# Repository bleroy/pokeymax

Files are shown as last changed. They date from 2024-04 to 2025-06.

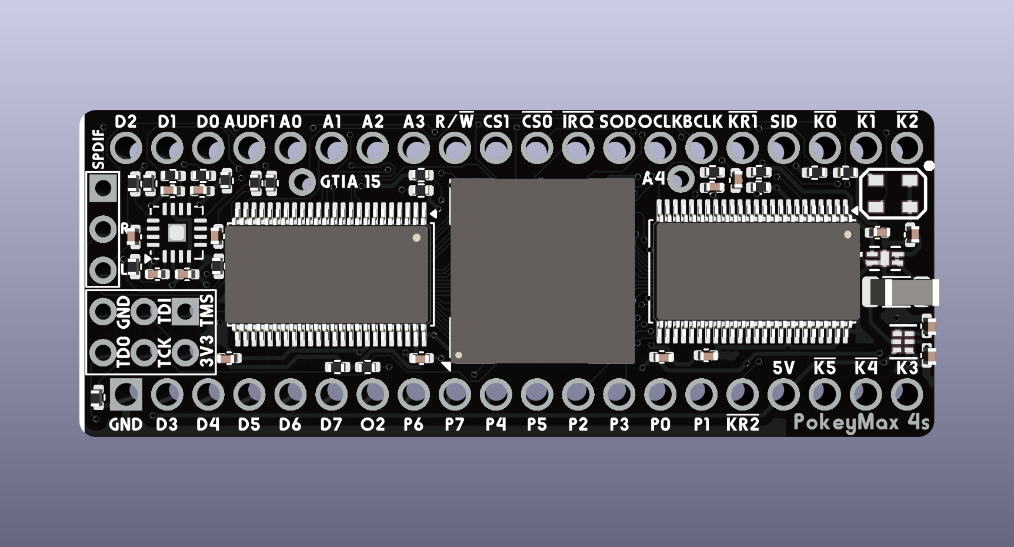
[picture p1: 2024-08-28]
PokeyMax4s/PokeyMax4s-front.png

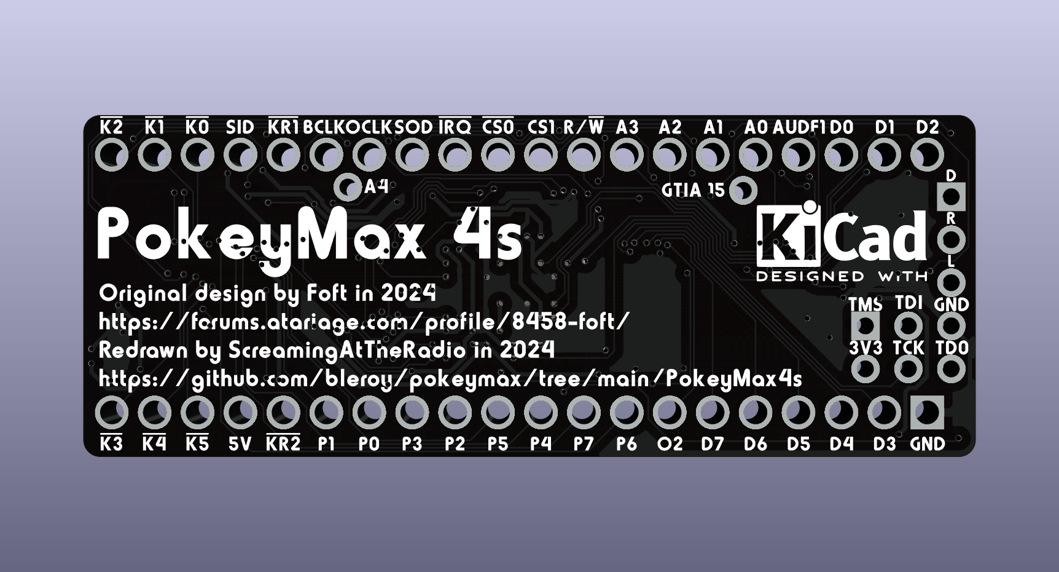
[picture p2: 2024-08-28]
PokeyMax4s/PokeyMax4s-back.png

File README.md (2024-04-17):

# PokeyMax 4

Foft's public designs for PokeyMax.

Pokeys are getting rare and expensive. FPGA alternatives exist but are also expensive. Foft, the author of PokeyMax, has very generously made his designs public on [the AtariAge forums](https://forums.atariage.com/topic/364870-pokeymax-v4-bring-up-thread/).
With his permission, I'm publishing his latest iteration on PokeyMax, version 4, which is a 2-layer version with all components on the top side. This should be easier to produce at a lower cost than the previous versions. I've also imported the project in KiCad from the original Eagle files.

Foft has not specified a license for his work, but attribution should be maintained. This is his design, reproduced here under his permission.

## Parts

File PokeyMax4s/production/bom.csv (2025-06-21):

Designator | Footprint | Quantity | Value | LCSC Part #
C1, C11, C2, C5, C6 | 0402 | 5 | 0.1uF | C60474
C10 | 0402 | 1 | 10nF | C60133
C12, C3, C4, C8 | 0402 | 4 | 2.2uF | C12530
C13, C14, C15 | 0402 | 3 | 18nF | C576736
C7 | 0402 | 1 | 1nF | C106205
C9 | 0402 | 1 | 4.7uF | C307423
FB1 | 0402 | 1 | R-EU_R0402 | C160612
L1 | 1206 | 1 | 1uH | C139248
R1, R14, R15, R16, R2, R4, R5 | 0402 | 7 | 10k | C2906885
R10, R6 | 0402 | 2 | 1k1 | C25860
R11, R12, R13 | 0402 | 3 | 560R | C2909370
R17, R18, R19 | 0402 | 3 | 20k | C25545
R3 | 0402 | 1 | 1k | C2906899
R7 | 0402 | 1 | 2k2 | C25933
R8, R9 | 0402 | 2 | 3k3 | C25936
REG1 | DRY6 | 1 | TPS62237DRYR | C398923
REG2 | TDFN4_1P2X1P6_MCH | 1 | MIC94310-JYMT-TR | C622559
U1 | VQFN-16-1EP_3x3mm_P0.5mm_EP1.1x1.1mm | 1 | TSV854IQ4T | C183029
U2, U4 | TSSOP-48_6.1x12.5mm_P0.5mm | 2 | 74CB3T16210 | C2674635
U3 | BGA-169_11.0x11.0mm_Layout13x13_P0.8mm_Ball0.5mm_Pad0.4mm_NSMD | 1 | MAX10 | C1521844
X1 | ASE | 1 | 50MHz | C7431354

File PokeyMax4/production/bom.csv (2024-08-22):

Designator | Footprint | Quantity | Value | LCSC Part #
C1, C11, C2, C5, C6 | C0402 | 5 | 0.1uF | C88219
C10 | C0402 | 1 | 0.01uF | C43253
C12, C3, C4, C8 | C0402 | 4 | 2.2uF | C43922
C13, C14, C15 | C0402 | 3 | 18nF | C107079
C7 | C0402 | 1 | 1nF | C1636
C9 | C0402 | 1 | 4.7uF | C112433
FB1 | R0402 | 1 | R-EU_R0402 | C710330
L1 | INDC1008X04 | 1 | LQM2HPN1R0MJ0L | C216157
R1, R2, R4, R5 | R0402 | 4 | 10K | C103199
R10, R6 | R0402 | 2 | 1k1 | C140120
R11, R12, R13 | 0402 | 3 | 560R
R14, R15, R16 | 0402 | 3 | 10k
R17, R18, R19 | 0402 | 3 | 20k
R3 | R0402 | 1 | 1K | C107079
R7 | R0402 | 1 | 2k2 | C294652
R8, R9 | R0402 | 2 | 3k3 | C72816
REG1 | DRY6 | 1 | TPS62237DRYR | C398923
REG2 | TDFN4_1P2X1P6_MCH | 1 | MIC94310-JYMT-TR | C622559
U1 | QFN50P300X300X100-16N | 1 | TSV854IQ4T | C2058240
U2, U4 | 56TVSOP_SMALL | 2 | SN74CB3T16211SM | C2674751
U3 | U169SMALL | 1 | MAX10 | C1521935
X1 | ASE | 1 | ASE | C7431354

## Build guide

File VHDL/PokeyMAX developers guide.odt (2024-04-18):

# PokeyMAX developers guide (for core version v1.26)

The PokeyMAX may contain several audio chips, depending on the version

## Memory map

$D200-$D20F | Pokey1
$D210-$D21F | Pokey2/Configuration
$D220-$D22F | Pokey3
$D230-$D23F | Pokey4
$D240-$D25F | SID1
$D260-$D27F | SID2
$D280-$D283 | COVOX
$D284-$D29F | SAMPLE
$D2A0-$D2AF | PSG1
$D2B0-$D2BF | PSG2
$D2C0-$D2FF | RESERVED

## Reduced memory maps

### Mono (or any PokeyMAX when in mono mode)

$D200-$D20F | Pokey1
$D210-$D2FF | Shadows of Pokey1

### Stereo

$D200-$D20F | Pokey1
$D210-$D21F | Pokey2/Configuration
$D220-$D2FF | Shadows of Pokey1, then Pokey2, then Pokey1 etc

### Stereo with covox

$D200-$D20F | Pokey1
$D210-$D21F | Pokey2/Configuration
$D220-$D27F | Shadows of Pokey1, then Pokey2, then Pokey1 etc
$D280-$D29F | COVOX
$D2A0-$D2FF | Shadows of Covox

### Quad

$D200-$D20F | Pokey1
$D210-$D21F | Pokey2/Configuration
$D220-$D22F | Pokey3
$D230-$D23F | Pokey4
$D240-$D2FF | Shadows of Pokey1, then Pokey2, then Pokey3, then Pokey4 etc

### Quad with covox

$D200-$D20F | Pokey1
$D210-$D21F | Pokey2/Configuration
$D220-$D22F | Pokey3
$D230-$D23F | Pokey4
$D240-$D27F | Shadows of Pokey1, then Pokey2, then Pokey3, then Pokey4 etc
$D280-$D29F | COVOX
$D2A0-$D2FF | Shadows of Covox

### Quad with sid

$D200-$D20F | Pokey1
$D210-$D21F | Pokey2/Configuration
$D220-$D22F | Pokey3
$D230-$D23F | Pokey4
$D240-$D25F | SID1
$D260-$D27F | SID2
$D280-$D2FF | Shadow of all above

## Pokey registers

Please see wikipedia , Altirra hardware reference manual or Mapping the Atari etc

https://en.wikipedia.org/wiki/POKEY

http://www.virtualdub.org/downloads/Altirra%20Hardware%20Reference%20Manual.pdf

https://www.atariarchives.org/mapping/

IRQ is by default connected only on pokey1, though there is a register that allows all pokeys to be connected.

Pots/keyboard are only connected to pokey1.

Pokey 1 and pokey 3 go to the left channel (and internal channel).

Pokey 2 and pokey 4 go to the right channel.

## SID registers

Please see the C64 wiki

https://www.c64-wiki.com/wiki/SID

Sid 1 goes to the left channel

Sid 2 goes to the right channel

Sid is clocked at a approximately 1MHz. It is an fraction of phi2. 5/9 phi2 in PAL mode, 4/7 phi2 in NTSC mode.

## PSG registers

Please see the YM2149 data sheet or other PSG implementation. Note that the registers here are directly memory mapped.

i.e. you can simply read/write $D2A0 for R0 and $D2AF for RF

The PSG is clocked at 1MHz, 2MHz or PHI2.

1MHz is generated by 5/9 phi2 in PAL mode, 4/7 phi2 in NTSC mode.

2MHz is generated by 10/9 phi2 in PAL mode, 8/7 phi2 in NTSC mode.

The number of steps in the envelope can be switched between 16 and 32.

Also the stereo modes can be adjusted.

Mono: All channels to left and right

Polish (default): A+B to left, B+C to right. The same for both chips.

Czech mode: A+C to left, B+C to right. The same for both chips.

Max mode: PSG 1 to left, PSG 2 to right

## COVOX registers

### $D280 – VOLONLYCH1 – R/W

128 | 64 | 32 | 16 | 8 | 4 | 2 | 1
V | V | V | V | V | V | V | V

Default: 0

#### V

Unsigned(0-255) – Current channel volume. For cpu manual sample playing. Left channel.

### $D281 – VOLONLYCH2– R/W

128 | 64 | 32 | 16 | 8 | 4 | 2 | 1
V | V | V | V | V | V | V | V

Default: 0

#### V

Unsigned(0-255) – Current channel volume. For cpu manual sample playing. Right channel.

### $D282 – VOLONLYCH3 – R/W

128 | 64 | 32 | 16 | 8 | 4 | 2 | 1
V | V | V | V | V | V | V | V

Default: 0

#### V

Unsigned(0-255) – Current channel volume. For cpu manual sample playing. Right channel.

### $D283 – VOLONLYCH4– R/W

128 | 64 | 32 | 16 | 8 | 4 | 2 | 1
V | V | V | V | V | V | V | V

Default: 0

#### V

Unsigned(0-255) – Current channel volume. For cpu manual sample playing. Left channel.

## SAMPLE registers

The sample player is an extended version of covox. It plays via DMA from 42KiB of internal ram. The 6502 must manually load this internal ram, after which samples may be repeatedly played back from it.

There are 3 data formats:

1. 4 bit signed
2. 8 bit signed
3. 4 bit ima adpcm, giving ~13bit quality. This may be created using for example sox under linux:
- sox -t wav some.wav -t ima -e ima-adpcm some.ima trim 0s 16384s

Sample rates up to 48KHz are supported (must higher is possible, but memory space is limited).

Samples are played by specifying a memory address, period, length and volume. The address and length are buffered, the period and volume are applied immediately.

When samples come to the end an irq is raised, which allows the next sample to be loaded into address and length. If a new sample has not been loaded the previous one is played.

The core clock speed is 2*phi2. So ~3.6MHz and varies with PAL/NTSC.

$D280-D283: See covox. Note that these are also updated by DMA from block ram, if enabled.

### $D284 – RAMADDRL– R/W

128 | 64 | 32 | 16 | 8 | 4 | 2 | 1
L7 | L6 | L5 | L4 | L3 | L2 | L1 | L0

Default: 0

### $D285 – RAMADDRH– R/W

128 | 64 | 32 | 16 | 8 | 4 | 2 | 1
L15 | L14 | L13 | L12 | L11 | L10 | L9 | L8

Default: 0

#### L0-15

Address in block ram, to read or write data

### $D286 – RAMDATA– R/W

128 | 64 | 32 | 16 | 8 | 4 | 2 | 1
D | D | D | D | D | D | D | D

#### D

Read/write data from/to the internal memory, at the address specified by RAMADDR

### $D287 – RAMDATAINC – W

128 | 64 | 32 | 16 | 8 | 4 | 2 | 1
D | D | D | D | D | D | D | D

#### D

Write data to the internal memory, at the address specified by RAMADDR. After each write the RAMADDR is incremented by 1.

### $D288 – CHANSEL – W

128 | 64 | 32 | 16 | 8 | 4 | 2 | 1
X | X | X | X | X | C | C | C

Default:0

#### C

Select the channel to set the address/period/length/volume of

1: channel 1

2: channel 2

3: channel 3

4: channel 4

Other: reserved.

### $D289 – SAMADDRL – W

128 | 64 | 32 | 16 | 8 | 4 | 2 | 1
L | L | L | L | L | L | L | L

### $D28A – SAMADDRG – W

128 | 64 | 32 | 16 | 8 | 4 | 2 | 1
H | H | H | H | H | H | H | H

Default:0

#### L/H

Set the address of the sample for the channel selected in CHANSEL. This register is applied at the end of the current sample, or when dma state is changed.

### $D28B – SAMLENL – W

128 | 64 | 32 | 16 | 8 | 4 | 2 | 1
L | L | L | L | L | L | L | L

### $D28C – SAMLENG – W

128 | 64 | 32 | 16 | 8 | 4 | 2 | 1
H | H | H | H | H | H | H | H

Default:0

#### L/H

Set the length of the sample for the channel selected in CHANSEL. This register is applied at the end of the current sample, or when dma state is changed.

This length is specified in number of samples.

Length = L+H*256 +1

### $D28D – SAMPERL – W

128 | 64 | 32 | 16 | 8 | 4 | 2 | 1
L | L | L | L | L | L | L | L

### $D28E – SAMPERG – W

128 | 64 | 32 | 16 | 8 | 4 | 2 | 1
H | H | H | H | H | H | H | H

Default:0

#### L/H

Set the period of the sample for the channel selected in CHANSEL. This register is applied at the end of the current period.

The next sample is played after this period expires. 2*PHI2/(L+H*256).

i.e. this sets the rate of sample playback

### $D28F – SAMVOL– W

128 | 64 | 32 | 16 | 8 | 4 | 2 | 1
X | X | V | V | V | V | V | V

Default:0

#### V

Set the volume from 0 (min) to 63 (max) for the channel selected in CHANSEL. The volume is linear.

### $D290 – SAMDMA– W

128 | 64 | 32 | 16 | 8 | 4 | 2 | 1
X | X | X | X | D | D | D | D

Default:0

#### D

Enable DMA on a per channel basis.

XXX0 (0) = Channel 1 dma off

XXX1 (1) = Channel 1 dma on

XX1X (2) = Channel 2 dma on

X1XX (4) = Channel 3 dma on

1XXX (8) = Channel 4 dma on

### $D291 – SAMIRQEN– R/W

128 | 64 | 32 | 16 | 8 | 4 | 2 | 1
X | X | X | X | I | I | I | I

Default:0

#### I

Enable IRQ on a per channel basis.

XXX0 (0) = Channel 1 irq off

XXX1 (1) = Channel 1 irq on

XX1X (2) = Channel 2 irq on

X1XX (4) = Channel 3 irq on

1XXX (8) = Channel 4 irq on

### $D292 – SAMIRQACT – R/W

128 | 64 | 32 | 16 | 8 | 4 | 2 | 1
X | X | X | X | I | I | I | I

#### I

Read if IRQ is active per channel

Write 0 to clear IRQ on a per channel basis.

XXX1 (1) = Channel 1 irq active

XX1X (2) = Channel 2 irq active

X1XX (4) = Channel 3 irq active

1XXX (8) = Channel 4 irq active

### $D293 – SAMCFG – R/W

128 | 64 | 32 | 16 | 8 | 4 | 2 | 1
B | B | B | B | A | A | A | A

Default: 0xf0

#### A

Enable IMA-ADPCM mode (16-bit sample encoded into 4-bits, approx 12-bit quality)

XXX1 (1) = Channel 1 adpcm mode

XX1X (2) = Channel 2 adpcm mode

X1XX (4) = Channel 3 adpcm mode

1XXX (8) = Channel 4 adpcm mode

#### B

The channels can be 8-bit (1) or 4-bit (0) quality.

XXX1 (16) = Channel 1 8-bit (0 for 4-bit)

XX1X (32) = Channel 2 8-bit

X1XX (64) = Channel 3 8-bit

1XXX (128) = Channel 4 8-bit

## Configuration registers

Configuration registers may be accessed by bank switching it into the $D210-$D21F range. This is done by writing a special value of 0x3f to $D20c.

Reserved locations (X) must be written as 0. Reserved locations will read as 0.

The values to set are shown as X(Y) where X is the bit values (must be shifted into place) and Y is the decimal value.

### $D210 –MODE – R/W

128 | 64 | 32 | 16 | 8 | 4 | 2 | 1
X | X | PAL | MonoDet | IRQEna | ChannelMode | X | Saturate

Miscellaneous settings

Default: 49

#### [Pokey] ChannelMode

0 (0) = Each pokey outputs as a separate ‘chip’

1 (4) = Output each pokey channel separately. E.g. channel 1 on AUD, channel 2 on audio pin 1, channel 3 on audio pin 2 and channel 4 on audio pin 3. In the case of multiple pokey chips, the channels are summed.

#### [Pokey] Saturate

0 (0) = Linear saturation curve

1(1) = Pokey saturation curve

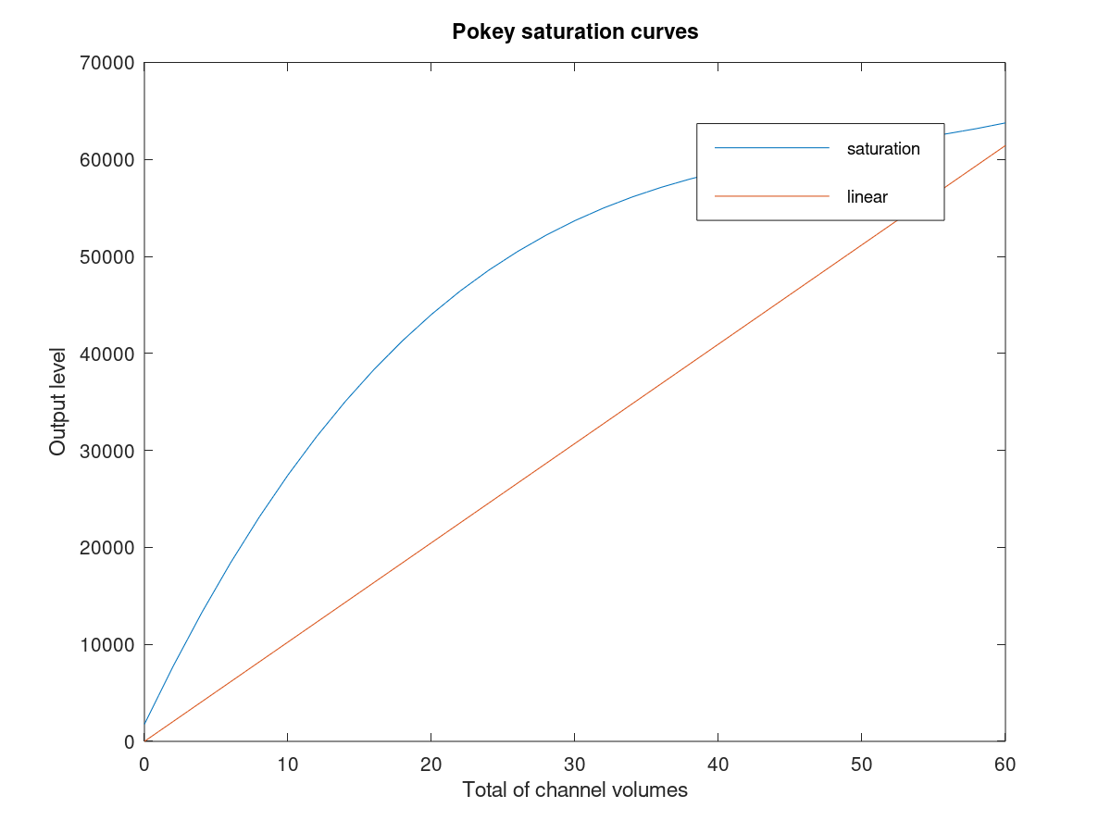
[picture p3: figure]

In future firmware revisions we anticipate allowing custom saturation curves.

#### IRQEna

0 (0) = Only pokey 1 irq is enabled

1(8) = All IRQs are enabled

#### MonoDet

0 (0) = Left channel to left, right channel to right

1(16) = When right channel is silent, play left on both left and right.

#### PAL

0 (0) = NTSC: Use 4/7 PHI2 multiplier for 1MHz clock

1(32) = PAL: Use 5/9 PHI2 multipler for 1MHz clock

### $D211 – CAPABILITY - RO

128 | 64 | 32 | 16 | 8 | 4 | 2 | 1
X | FLASH | SAMPLE | COVOX | PSG | SID | Pokey | Pokey

Default: device specific

#### Pokey

00 (0) = Device contains a single pokey

01 (1) = Device contains two pokeys

10 (2) = Device contains four pokeys

#### SID

0(0) = Device does not contain a SID

1(4) = Device contains two SID chips

#### PSG

0(0) = Device does not contain a PSG

1(8) = Device contains two PSG chips

#### COVOX

0(0) = Device does not contain a COVOX

1(16) = Device contains four 8-bit COVOX manual volume registers

#### SAMPLE

0(0) = Device does not contain a sample player

1(32) = Device contains a block ram based sample player, with 32KB of memory

#### FLASH

0(0) = Device does not support reading or writing flash contents

1(64) = Device supports flash memory access (UFM and CFM)

## $D212 – POSTDIVIDE – RW

128 | 64 | 32 | 16 | 8 | 4 | 2 | 1
CH3 | CH3 | CH2 | CH2 | CH1 | CH1 | CH0 | CH0

Default: 160

PokeyMAX natively outputs 0-5V on each audio output. A single audio chip at max volume will be 5V and at min volume 0V.

For internal output into the Atari pin 37 this is correct.

For line level output we want closer to 1V, this register allows us to achieve this by dividing selected channels by 2, 4 or 8, giving 0-2.5V, 0-1.25V or 0-0.0675V.

NB: When multiple devices are outputting at once, we could have a range of 0-10V, 0-20V or even 0-50V! Note that the pokeymax can natively only output 0-5V so anything above 5V will saturate. By using the /4 you will be able to have 4 devices at maximum volume with no distortion.

#### CH0

00(0) = /1

01(1) = /2

10(2) = /4

11(3) = /8

#### CH1

00(0) = /1

01(4) = /2

10(8) = /4

11(12) = /8

#### CH2

00(0) = /1

01(16) = /2

10(32) = /4

11(48) = /8

#### CH3

00(0) = /1

01(64) = /2

10(128) = /4

11(192) = /8

## $D213 – GTIAEN - RW

128 | 64 | 32 | 16 | 8 | 4 | 2 | 1
X | X | X | X | CH3 | CH2 | CH1 | CH0

Default: 12

This register allows mixing gtia into the output channels.

Typically this is done for the channels actual to phono connectors and not for channels directly outputting into the system, since the motherboard already mixes gtia.

#### CH0

0(0)=gtia not included in channel 0

0(1)=gtia included in channel 0

#### CH1

0(0)=gtia not included in channel 1

1(2)=gtia included in channel 1

#### CH2

0(0)=gtia not included in channel 2

1(4)=gtia included in channel 2

#### CH3

0(0)=gtia not included in channel 3

1(8)=gtia included in channel 3

## $D214 – VERSION – R/ VERSIONLOC –W

##### W

128 | 64 | 32 | 16 | 8 | 4 | 2 | 1
X | X | X | X | X | LOC | LOC | LOC

Default: 0

#### LOC

Write a value from 0-7 for the byte to read from the version string

##### R

128 | 64 | 32 | 16 | 8 | 4 | 2 | 1
CHAR | CHAR | CHAR | CHAR | CHAR | CHAR | CHAR | CHAR

Default: NA (depends on version!)

#### CHAR

Read a single character from the version string.

e.g. write 0, then read character 0, write 1 then read character 1 etc.

## $D215 – PSGMODE - RW

128 | 64 | 32 | 16 | 8 | 4 | 2 | 1
X | VOLP | VOLP | ENV16 | STEREO | STEREO | FREQ | FREQ

Default: 4

This register allows changing settings for the PSG chips

#### FREQ

00(0)=2MHz

01(1)=1MHz

10(2)=1.7MHz

11(3)=reserved

#### STEREO

00(0)=mono. All channels of both chips to left and right

01(4)=Polish standard. A+B to left, B+C to right. For both chips.

10(8)=Czech standard. A+C to left, B+C to right. For both chips

11(12)=chip 1 to left, chip 2 to right.

#### ENV16

0(0)=32 step envelope

1(16)=16 step envelope

#### VOLP

00(0)=Log volume

11(96)=Linear volume

Space reserved for YM/AY3 curves.

## $D216 – SIDMODE - RW

128 | 64 | 32 | 16 | 8 | 4 | 2 | 1
X | X | D2 | T2 | X | X | D1 | T1

Default: 17

This register allows changing settings for the SID chips. This changes the filter curve linear to approximate the very non-linear 6581 curve. It also changes the mixed waveforms and enables 6581 filter distortion. Digifix may also be enabled/disabled for the 8580.

#### T1 Sid 1

0(0)=8580 (linear filter)

1(1)=6581

#### D1 Sid 1

0(0)=digifix off

1(1)=digifix on

#### T2 Sid 2

0(0)=8580 (linear filter)

1(16)=6581

#### D2 Sid 2

0(0)=digifix off

1(32)=digifix on

## $D217 – RESTRICT - RW

128 | 64 | 32 | 16 | 8 | 4 | 2 | 1
X | X | X | SAMPLE | PSG | SID | POKEY | POKEY

Default: 31

Allows disabling sound chips via software. This is used by the U1MB plugin.

#### POKEY

00(0)=Mono

01(1)=Stereo (if off area replaced by pokey1)

10(2)=Quad (if off area replaced by pokey1)

#### SID

0(0)=SID area replaced by pokey 1

1(4)=SID on

#### PSG

0(0)=PSG area replaced by pokey 1

1(8)=PSG on

#### SAMPLE

0(0)=COVOX/SAMPLE area replaced by pokey 1

1(8)=COVOX/SAMPLE on

## $D218-$D21A RESERVED

Do not read or write

## $D20C/$D21C – ID –R

## $D20C/$D21C - CONFIG - W

##### W

128 | 64 | 32 | 16 | 8 | 4 | 2 | 1
CFGEN | CFGEN | CFGEN | CFGEN | CFGEN | CFGEN | CFGEN | CFGEN

#### CFGEN

00111111(63) –Map configuration into the $D210-$D21F memory area

Others values - $D210-$D21F is unchanged

##### R

128 | 64 | 32 | 16 | 8 | 4 | 2 | 1
ID | ID | ID | ID | ID | ID | ID | ID

Default: 1

ID

Returns 1 if pokeymax installed

## FLASH

The following registers are only present if there is flash support. These are for Retronics use for updates. In 10M02 devices these are not supported. In 10M04 and 10M08 devices they are supported. Cores may be flashed or register defaults changed using the pokeycfg.xex program.

The flash is used for storing the FPGA core and register default contents. In future it will also be used for SID ‘corrupt’ mixed waveforms, volume curve data, SID filter curves and possibly some standard samples for the sample player.

The flash has a 32-bit parallel interface. See the Max10 flash guide for further details.

## $D21B – FLASHOP –RW

128 | 64 | 32 | 16 | 8 | 4 | 2 | 1
X | X | A16 | A15 | A14 | CFG | REQ | R/W_N

Default:0

#### R/W_N

0(0)=write to flash data or cfg (must erase first)

1(1)=read from flash data or cfg

#### REQ

0(0)=Do not make a 32-bit wide request to the flash controller.

1(2)=Make a new 32-bit wide request to the flash controller. Once it is complete, REQ is cleared. For reads you can expect data to be available in the 32-bit FLASHDAT register by the next cycle. Writes/erases may takes longer. Writes takes data from the 32-bit FLASHDAT register.

#### CFG

0(0)=Access data area (i.e. main flash data).

1(4)=Access cfg area. This consists of two special registers in the max 10 for status, write protect and page/sector erase.

## $D21D – FLASHADL -RW

128 | 64 | 32 | 16 | 8 | 4 | 2 | 1
A5 | A4 | A3 | A2 | A1 | A0 | WIN | WIN

Default:0

Read/write to bits 7 downto 0 of the flash address register.

WIN: Window into FLASHDAT (when combined with A15-A0 32-bit address effectively makes a virtual A17-A0 8-bit address)

A15-A0: Flash memory address

## $D21E – FLASHADH - RW

128 | 64 | 32 | 16 | 8 | 4 | 2 | 1
A13 | A12 | A11 | A10 | A9 | A8 | A7 | A6

Default:0

Read/write to bits 15 downto 8 of the flash address register.

## $D21F – FLASHDAT -RW

Default:0

Read/write from/to 8-bit window into 32-bit configuration register.

The address in the register is specified by the 2 low bits of FLASHADL.

Contents are changed either by the CPU or by a flash read operation.

On a flash write operation the contents of this register is written.

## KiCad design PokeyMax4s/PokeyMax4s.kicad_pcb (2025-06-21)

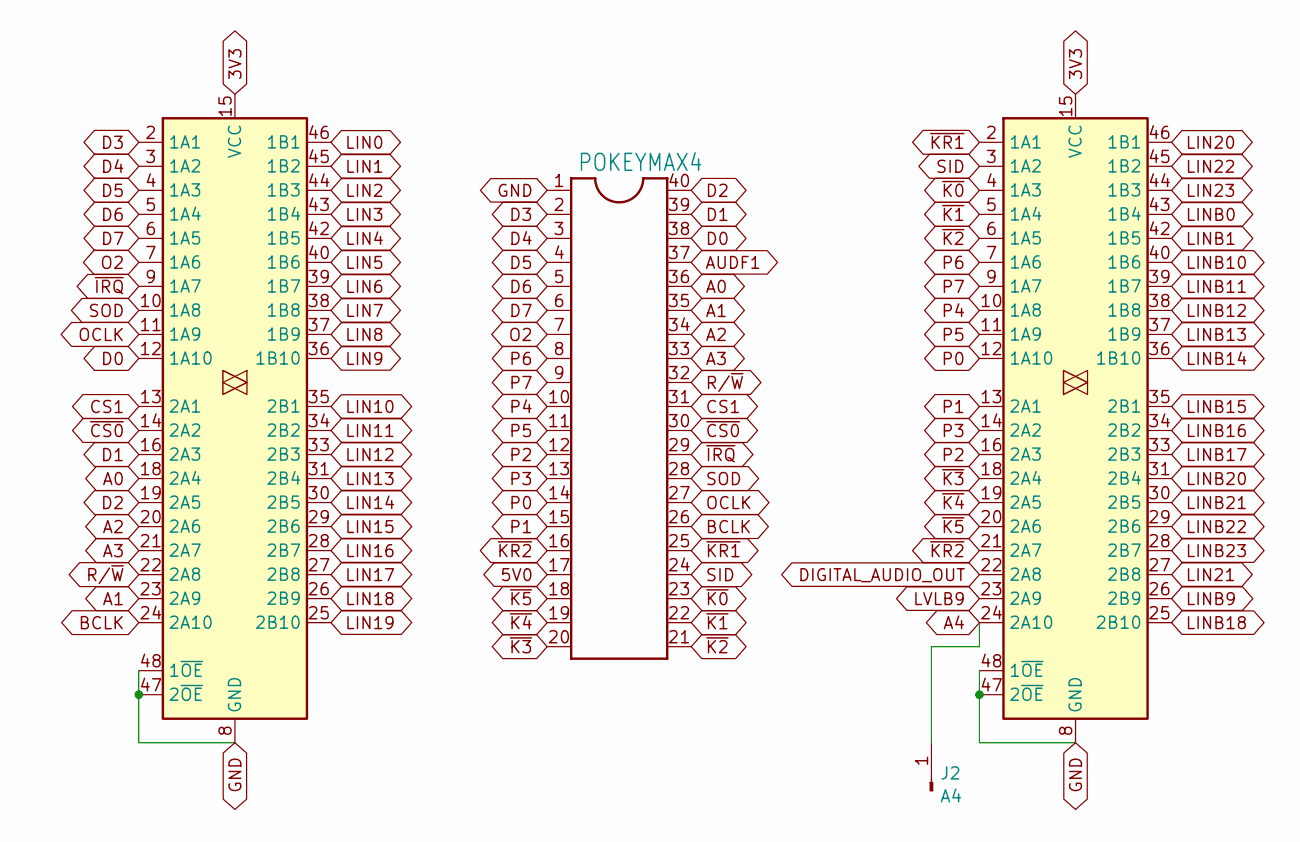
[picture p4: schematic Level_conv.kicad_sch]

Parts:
J2: A4; PinHeader_1x01_P2.54mm_Vertical
POKEYMAX4: DIL40; DIP-40_W15.24mm_Socket
U2, U4: 74CB3T16210; TSSOP-48_6.1x12.5mm_P0.5mm; LCSC Part # C2674635

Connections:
3V3: U2.15 (VCC), U4.15 (VCC); also elsewhere on the board
5V0: POKEYMAX4.17; also elsewhere on the board
A0: POKEYMAX4.36, U4.18 (2A4)
A1: POKEYMAX4.35, U4.23 (2A9)
A2: POKEYMAX4.34, U4.20 (2A6)
A3: POKEYMAX4.33, U4.21 (2A7)
A4: J2.1, U2.24 (2A10)
AUDF1: POKEYMAX4.37; also elsewhere on the board
BCLK: POKEYMAX4.26, U4.24 (2A10)
CS1: POKEYMAX4.31, U4.13 (2A1)
D0: POKEYMAX4.38, U4.12 (1A10)
D1: POKEYMAX4.39, U4.16 (2A3)
D2: POKEYMAX4.40, U4.19 (2A5)
D3: POKEYMAX4.2, U4.2 (1A1)
D4: POKEYMAX4.3, U4.3 (1A2)
D5: POKEYMAX4.4, U4.4 (1A3)
D6: POKEYMAX4.5, U4.5 (1A4)
D7: POKEYMAX4.6, U4.6 (1A5)
DIGITAL_AUDIO_OUT: U2.22 (2A8); also elsewhere on the board
GND: POKEYMAX4.1, U2.8 (GND), U2.17 (GND), U2.32 (GND), U2.41 (GND), U2.47 (2~OE), U2.48 (1~OE), U4.8 (GND), U4.17 (GND), U4.32 (GND), U4.41 (GND), U4.47 (2~OE), U4.48 (1~OE); also elsewhere on the board
LIN0: U4.46 (1B1); also elsewhere on the board
LIN1: U4.45 (1B2); also elsewhere on the board
LIN2: U4.44 (1B3); also elsewhere on the board
LIN3: U4.43 (1B4); also elsewhere on the board
LIN4: U4.42 (1B5); also elsewhere on the board
LIN5: U4.40 (1B6); also elsewhere on the board
LIN6: U4.39 (1B7); also elsewhere on the board
LIN7: U4.38 (1B8); also elsewhere on the board
LIN8: U4.37 (1B9); also elsewhere on the board
LIN9: U4.36 (1B10); also elsewhere on the board
LIN10: U4.35 (2B1); also elsewhere on the board
LIN11: U4.34 (2B2); also elsewhere on the board
LIN12: U4.33 (2B3); also elsewhere on the board
LIN13: U4.31 (2B4); also elsewhere on the board
LIN14: U4.30 (2B5); also elsewhere on the board
LIN15: U4.29 (2B6); also elsewhere on the board
LIN16: U4.28 (2B7); also elsewhere on the board
LIN17: U4.27 (2B8); also elsewhere on the board
LIN18: U4.26 (2B9); also elsewhere on the board
LIN19: U4.25 (2B10); also elsewhere on the board
LIN20: U2.46 (1B1); also elsewhere on the board
LIN21: U2.27 (2B8); also elsewhere on the board
LIN22: U2.45 (1B2); also elsewhere on the board
LIN23: U2.44 (1B3); also elsewhere on the board
LINB0: U2.43 (1B4); also elsewhere on the board
LINB1: U2.42 (1B5); also elsewhere on the board
LINB9: U2.26 (2B9); also elsewhere on the board
LINB10: U2.40 (1B6); also elsewhere on the board
LINB11: U2.39 (1B7); also elsewhere on the board
LINB12: U2.38 (1B8); also elsewhere on the board
LINB13: U2.37 (1B9); also elsewhere on the board
LINB14: U2.36 (1B10); also elsewhere on the board
LINB15: U2.35 (2B1); also elsewhere on the board
LINB16: U2.34 (2B2); also elsewhere on the board
LINB17: U2.33 (2B3); also elsewhere on the board
LINB18: U2.25 (2B10); also elsewhere on the board
LINB20: U2.31 (2B4); also elsewhere on the board
LINB21: U2.30 (2B5); also elsewhere on the board
LINB22: U2.29 (2B6); also elsewhere on the board
LINB23: U2.28 (2B7); also elsewhere on the board
LVLB9: U2.23 (2A9); also elsewhere on the board
O2: POKEYMAX4.7, U4.7 (1A6)
OCLK: POKEYMAX4.27, U4.11 (1A9)
P0: POKEYMAX4.14, U2.12 (1A10)
P1: POKEYMAX4.15, U2.13 (2A1)
P2: POKEYMAX4.12, U2.16 (2A3)
P3: POKEYMAX4.13, U2.14 (2A2)
P4: POKEYMAX4.10, U2.10 (1A8)
P5: POKEYMAX4.11, U2.11 (1A9)
P6: POKEYMAX4.8, U2.7 (1A6)
P7: POKEYMAX4.9, U2.9 (1A7)
R/~W: POKEYMAX4.32, U4.22 (2A8)
SID: POKEYMAX4.24, U2.3 (1A2)
SOD: POKEYMAX4.28, U4.10 (1A8)
~CS0: POKEYMAX4.30, U4.14 (2A2)
~IRQ: POKEYMAX4.29, U4.9 (1A7)
~K0: POKEYMAX4.23, U2.4 (1A3)
~K1: POKEYMAX4.22, U2.5 (1A4)
~K2: POKEYMAX4.21, U2.6 (1A5)
~K3: POKEYMAX4.20, U2.18 (2A4)
~K4: POKEYMAX4.19, U2.19 (2A5)
~K5: POKEYMAX4.18, U2.20 (2A6)
~KR1: POKEYMAX4.25, U2.2 (1A1)
~KR2: POKEYMAX4.16, U2.21 (2A7)

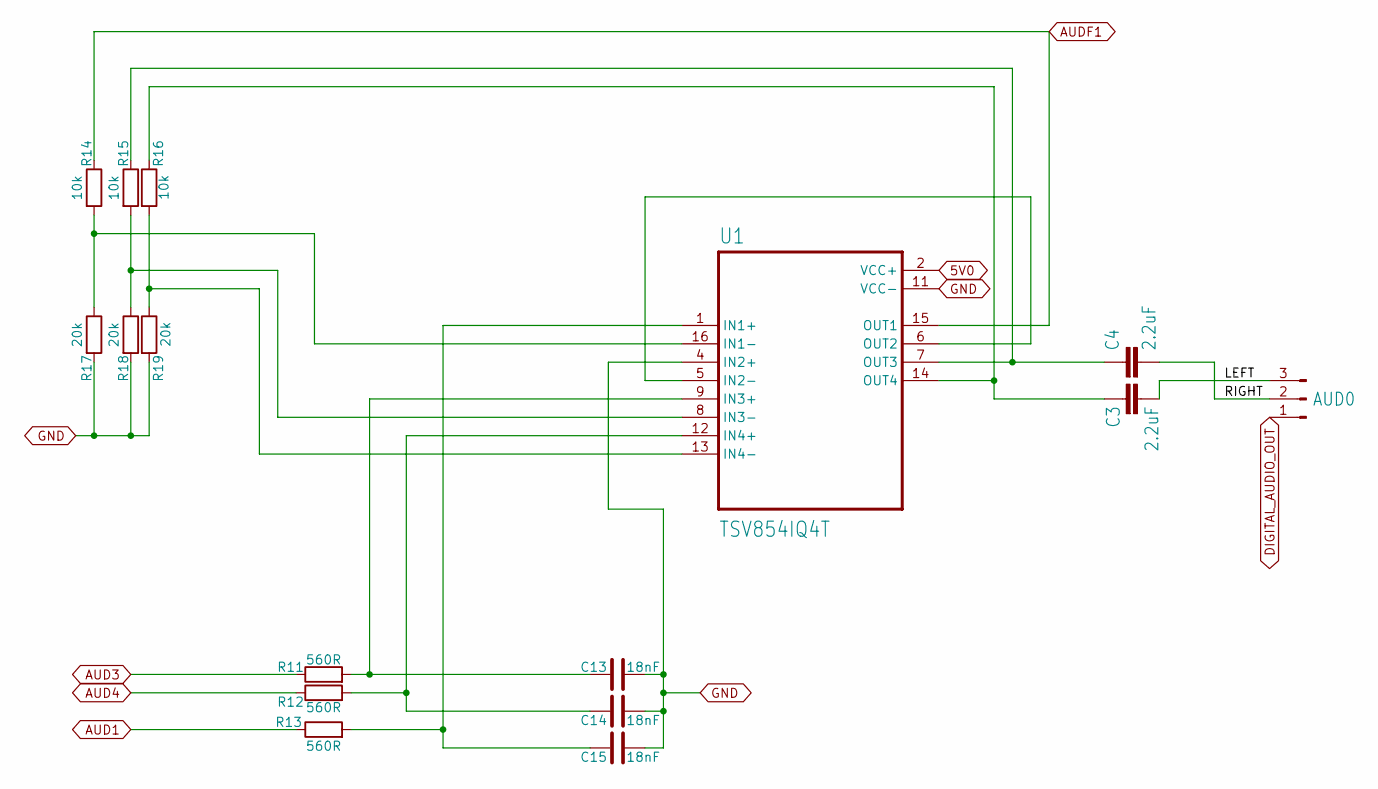
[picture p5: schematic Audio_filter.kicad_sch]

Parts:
AUD0: PINHD-2X2; PinHeader_1x03_P2.54mm_Vertical
C3, C4: 2.2uF; C_0402_1005Metric; LCSC Part # C12530
C13, C14, C15: 18nF; C_0402_1005Metric; LCSC Part # C576736
R11, R12, R13: 560R; R_0402_1005Metric; LCSC Part # C2909370
R14, R15, R16: 10k; R_0402_1005Metric; LCSC Part # C2906885
R17, R18, R19: 20k; R_0402_1005Metric; LCSC Part # C25545
U1: TSV854IQ4T; VQFN-16-1EP_3x3mm_P0.5mm_EP1.1x1.1mm; LCSC Part # C183029

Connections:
5V0: U1.2 (VCC+); also elsewhere on the board
/Audio filter/LEFT: AUD0.3, C3.2
/Audio filter/RIGHT: AUD0.2, C4.2
AUD1: R13.1; also elsewhere on the board
AUD3: R11.1; also elsewhere on the board
AUD4: R12.1; also elsewhere on the board
AUDF1: R14.1, U1.15 (OUT1); also elsewhere on the board
DIGITAL_AUDIO_OUT: AUD0.1; also elsewhere on the board
GND: C13.2, C14.2, C15.2, R17.2, R18.2, R19.2, U1.4 (IN2+), U1.11 (VCC-); also elsewhere on the board
unnamed: C15.1, R13.2, U1.1 (IN1+)
unnamed: R14.2, R17.1, U1.16 (IN1-)
unnamed: U1.5 (IN2-), U1.6 (OUT2)
unnamed: C13.1, R11.2, U1.9 (IN3+)
unnamed: R15.2, R18.1, U1.8 (IN3-)
unnamed: C14.1, R12.2, U1.12 (IN4+)
unnamed: R16.2, R19.1, U1.13 (IN4-)
unnamed: C4.1, R15.1, U1.7 (OUT3)
unnamed: C3.1, R16.1, U1.14 (OUT4)

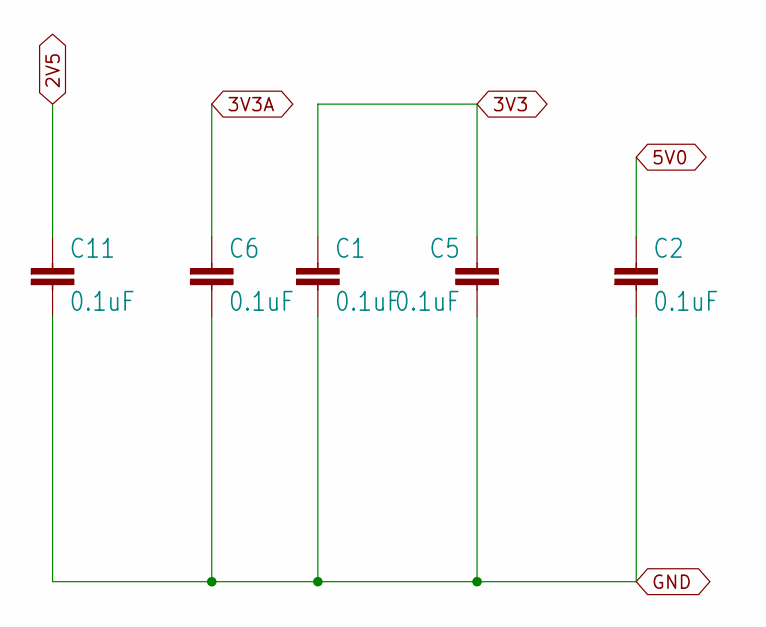
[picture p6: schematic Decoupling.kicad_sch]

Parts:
C1, C2, C5, C6, C11: 0.1uF; C_0402_1005Metric; LCSC Part # C60474

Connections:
2V5: C11.1; also elsewhere on the board
3V3: C1.1, C5.1; also elsewhere on the board
3V3A: C6.1; also elsewhere on the board
5V0: C2.1; also elsewhere on the board
GND: C1.2, C2.2, C5.2, C6.2, C11.2; also elsewhere on the board

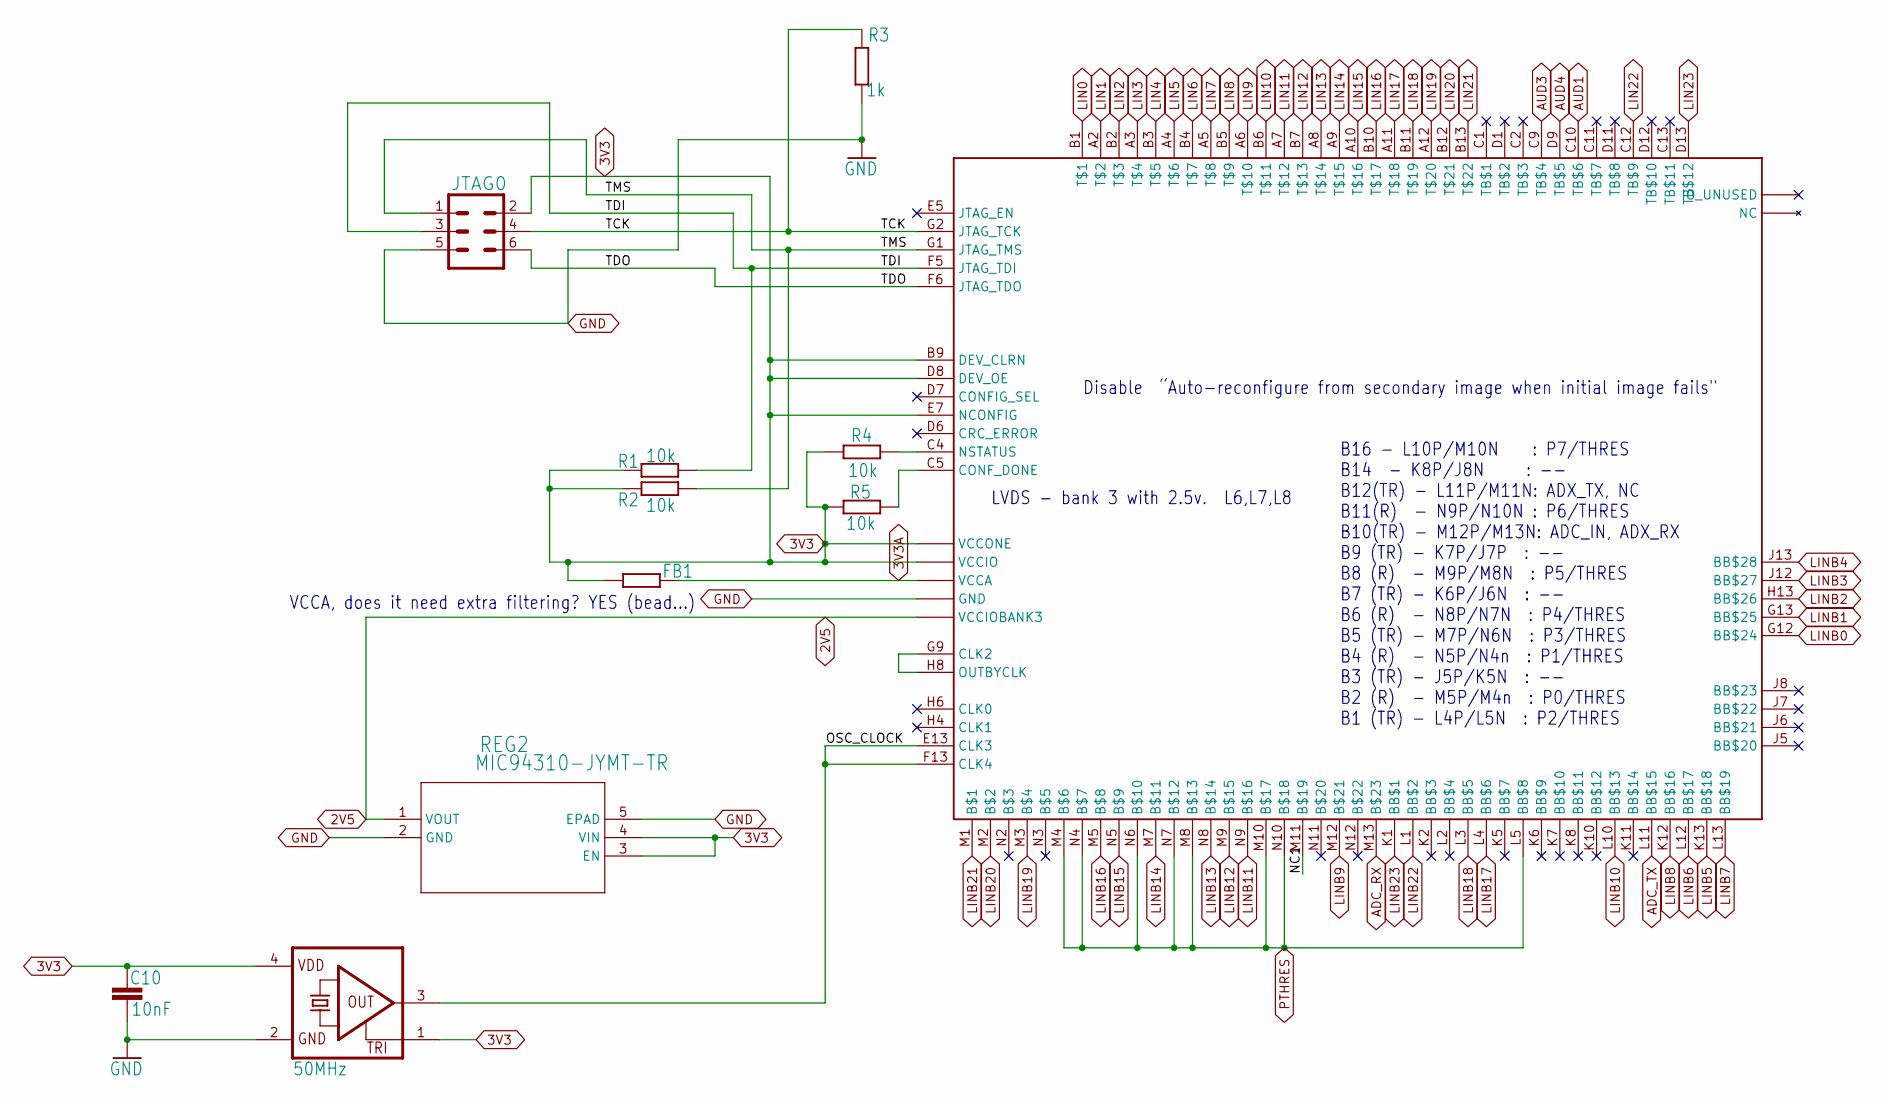
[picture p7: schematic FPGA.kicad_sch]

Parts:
C10: 10nF; C_0402_1005Metric; LCSC Part # C60133
FB1: R-EU_R0402; C_0402_1005Metric; LCSC Part # C160612
JTAG0: CONN_03X2LOCK; PinHeader_2x03_P2.54mm_Vertical
R1, R2, R4, R5: 10k; R_0402_1005Metric; LCSC Part # C2906885
R3: 1k; R_0402_1005Metric; LCSC Part # C2906899
REG2: MIC94310-JYMT-TR; TDFN4_1P2X1P6_MCH; LCSC Part # C622559
U3: MAX10; BGA-169_11.0x11.0mm_Layout13x13_P0.8mm_Ball0.5mm_Pad0.4mm_N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; LCSC Part # C1521844
X1: 50MHz; ASE; LCSC Part # C7431354

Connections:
2V5: REG2.1 (VOUT), U3.L6 (VCCIOBANK3), U3.L7 (VCCIOBANK3), U3.L8 (VCCIOBANK3); also elsewhere on the board
3V3: C10.1, FB1.1, JTAG0.2, R1.2, R2.2, R4.2, R5.1, REG2.3 (EN), REG2.4 (VIN), U3.B9 (DEV_CLRN), U3.C6 (VCCIO), U3.C7 (VCCIO), U3.C8 (VCCIO), U3.D8 (DEV_OE), U3.E7 (NCONFIG), U3.F2 (VCCIO), U3.F7 (VCCONE), U3.F11 (VCCIO), U3.G3 (VCCIO), U3.G6 (VCCONE), U3.G8 (VCCONE), U3.G11 (VCCIO), U3.H7 (VCCONE), U3.H11 (VCCIO), U3.J3 (VCCIO), U3.J11 (VCCIO), U3.K3 (VCCIO), X1.1 (TRI), X1.4 (VDD); also elsewhere on the board
3V3A: FB1.2, U3.D4 (VCCA), U3.D10 (VCCA), U3.K4 (VCCA), U3.K9 (VCCA); also elsewhere on the board
/FPGA/NC1: U3.M11
/FPGA/OSC_CLOCK: U3.E13 (CLK3), U3.F13 (CLK4), X1.3 (OUT)
/FPGA/TCK: JTAG0.4, R3.1, U3.G2 (JTAG_TCK)
/FPGA/TDI: JTAG0.3, R1.1, U3.F5 (JTAG_TDI)
/FPGA/TDO: JTAG0.6, U3.F6 (JTAG_TDO)
/FPGA/TMS: JTAG0.1, R2.1, U3.G1 (JTAG_TMS)
ADC_RX: U3.M13; also elsewhere on the board
ADC_TX: U3.L11 (BB$15); also elsewhere on the board
AUD1: U3.C10 (TB$6); also elsewhere on the board
AUD3: U3.C9 (TB$4); also elsewhere on the board
AUD4: U3.D9 (TB$5); also elsewhere on the board
GND: C10.2, JTAG0.5, R3.2, REG2.2 (GND), REG2.5 (EPAD), U3.A1 (GND), U3.A13 (GND), U3.B8 (GND), U3.C3 (GND), U3.D5 (GND), U3.E11 (GND), U3.F3 (GND), U3.G7 (GND), U3.H12 (GND), U3.J4 (GND), U3.L9 (GND), U3.M6 (GND), U3.N1 (GND), U3.N13 (GND), X1.2 (GND); also elsewhere on the board
LIN0: U3.B1; also elsewhere on the board
LIN1: U3.A2; also elsewhere on the board
LIN2: U3.B2; also elsewhere on the board
LIN3: U3.A3; also elsewhere on the board
LIN4: U3.B3; also elsewhere on the board
LIN5: U3.A4; also elsewhere on the board
LIN6: U3.B4; also elsewhere on the board
LIN7: U3.A5; also elsewhere on the board
LIN8: U3.B5; also elsewhere on the board
LIN9: U3.A6; also elsewhere on the board
LIN10: U3.B6; also elsewhere on the board
LIN11: U3.A7; also elsewhere on the board
LIN12: U3.B7; also elsewhere on the board
LIN13: U3.A8; also elsewhere on the board
LIN14: U3.A9; also elsewhere on the board
LIN15: U3.A10; also elsewhere on the board
LIN16: U3.B10; also elsewhere on the board
LIN17: U3.A11; also elsewhere on the board
LIN18: U3.B11; also elsewhere on the board
LIN19: U3.A12; also elsewhere on the board
LIN20: U3.B12; also elsewhere on the board
LIN21: U3.B13; also elsewhere on the board
LIN22: U3.C12 (TB$9); also elsewhere on the board
LIN23: U3.D13 (TB$12); also elsewhere on the board
LINB0: U3.G12 (BB$24); also elsewhere on the board
LINB1: U3.G13 (BB$25); also elsewhere on the board
LINB2: U3.H13 (BB$26)
LINB3: U3.J12 (BB$27)
LINB4: U3.J13 (BB$28)
LINB5: U3.K13 (BB$18)
LINB6: U3.L12 (BB$17)
LINB7: U3.L13 (BB$19)
LINB8: U3.K12 (BB$16)
LINB9: U3.M12; also elsewhere on the board
LINB10: U3.L10 (BB$13); also elsewhere on the board
LINB11: U3.N9; also elsewhere on the board
LINB12: U3.M9; also elsewhere on the board
LINB13: U3.N8; also elsewhere on the board
LINB14: U3.M7; also elsewhere on the board
LINB15: U3.N5; also elsewhere on the board
LINB16: U3.M5; also elsewhere on the board
LINB17: U3.L4 (BB$6); also elsewhere on the board
LINB18: U3.L3 (BB$5); also elsewhere on the board
LINB19: U3.M3
LINB20: U3.M2; also elsewhere on the board
LINB21: U3.M1; also elsewhere on the board
LINB22: U3.L1 (BB$2); also elsewhere on the board
LINB23: U3.K1 (BB$1); also elsewhere on the board
unnamed: U3.G9 (CLK2), U3.H8 (OUTBYCLK)
unnamed: R5.2, U3.C5 (CONF_DONE)
unnamed: R4.1, U3.C4 (NSTATUS)
PTHRES: U3.L5 (BB$8), U3.M4, U3.M8, U3.M10, U3.N4, U3.N6, U3.N7, U3.N10; also elsewhere on the board

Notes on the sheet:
Disable “Auto-reconfigure from secondary image when initial image fails"
B16 - L10P/M10N : P7/THRES B14 - K8P/J8N : -- B12(TR) - L11P/M11N: ADX_TX, NC B11(R) - N9P/N10N : P6/THRES B10(TR) - M12P/M13N: ADC_IN, ADX_RX B9 (TR) - K7P/J7P : -- B8 (R) - M9P/M8N : P5/THRES B7 (TR) - K6P/J6N : -- B6 (R) - N8P/N7N : P4/THRES B5 (TR) - M7P/N6N : P3/THRES B4 (R) - N5P/N4n : P1/THR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
LVDS - bank 3 with 2.5v. L6,L7,L8
VCCA, does it need extra filtering? YES (bead...)

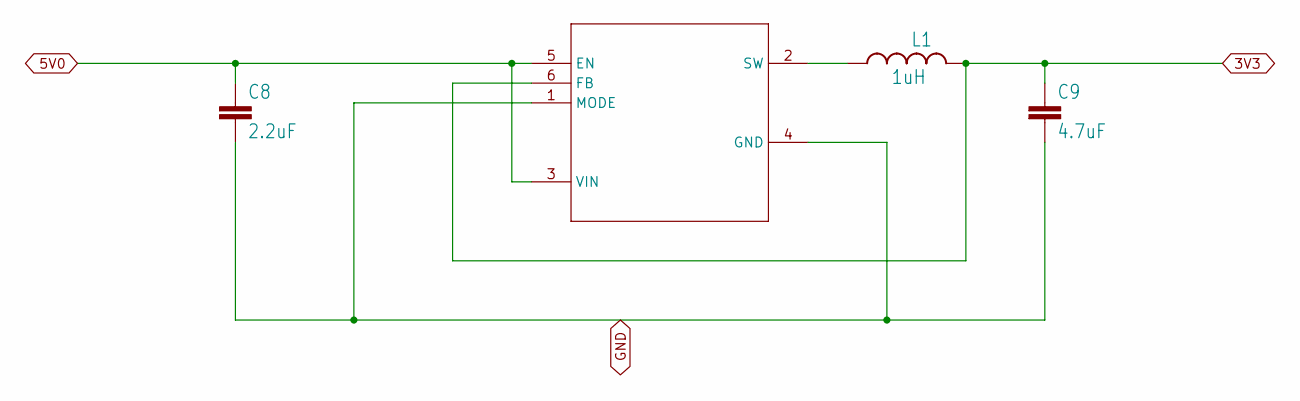
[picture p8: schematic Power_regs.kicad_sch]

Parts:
C8: 2.2uF; C_0402_1005Metric; LCSC Part # C12530
C9: 4.7uF; C_0402_1005Metric; LCSC Part # C307423
L1: 1uH; L_1206_3216Metric; LCSC Part # C139248
REG1: TPS62237DRYR; DRY6; LCSC Part # C398923

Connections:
3V3: C9.1, L1.2, REG1.6 (FB); also elsewhere on the board
5V0: C8.1, REG1.3 (VIN), REG1.5 (EN); also elsewhere on the board
GND: C8.2, C9.2, REG1.1 (MODE), REG1.4 (GND); also elsewhere on the board
unnamed: L1.1, REG1.2 (SW)

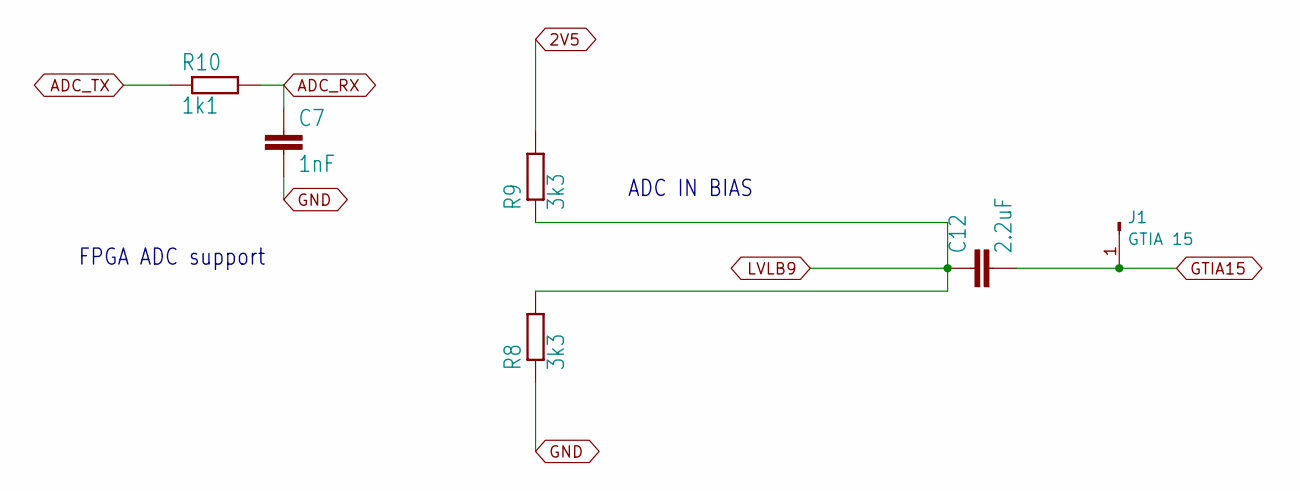
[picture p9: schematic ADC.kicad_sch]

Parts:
C7: 1nF; C_0402_1005Metric; LCSC Part # C106205
C12: 2.2uF; C_0402_1005Metric; LCSC Part # C12530
J1: GTIA 15; PinHeader_1x01_P2.54mm_Vertical
R8, R9: 3k3; R_0402_1005Metric; LCSC Part # C25936
R10: 1k1; R_0402_1005Metric; LCSC Part # C25860

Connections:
2V5: R9.2; also elsewhere on the board
ADC_RX: C7.1, R10.2; also elsewhere on the board
ADC_TX: R10.1; also elsewhere on the board
GND: C7.2, R8.1; also elsewhere on the board
GTIA15: C12.2, J1.1
LVLB9: C12.1, R8.2, R9.1; also elsewhere on the board

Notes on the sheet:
ADC IN BIAS
FPGA ADC support

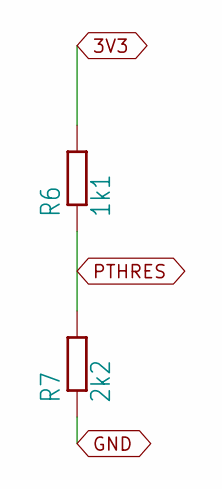
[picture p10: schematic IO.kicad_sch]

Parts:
R6: 1k1; R_0402_1005Metric; LCSC Part # C25860
R7: 2k2; R_0402_1005Metric; LCSC Part # C25933

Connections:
3V3: R6.2; also elsewhere on the board
GND: R7.1; also elsewhere on the board
PTHRES: R6.1, R7.2; also elsewhere on the board

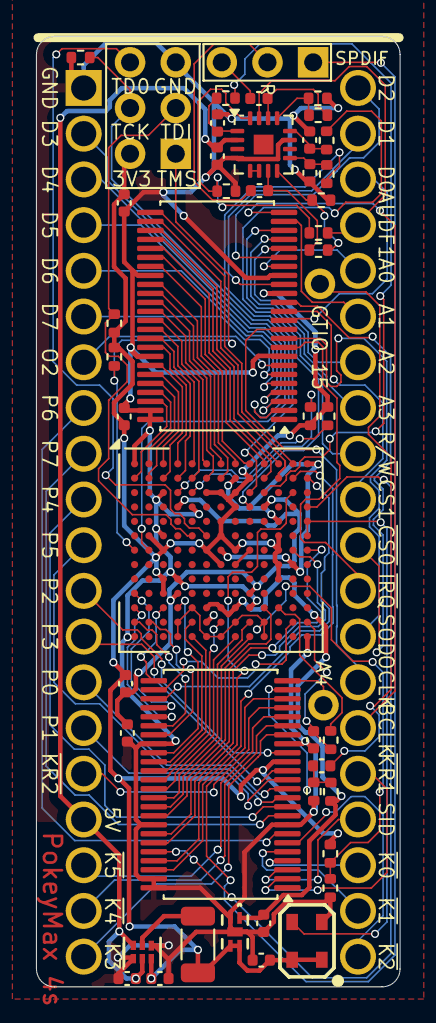
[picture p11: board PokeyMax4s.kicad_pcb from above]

Board: 2 copper layers, 20.2 x 52.8 mm, 48 parts (0 on the bottom side), 113 nets.

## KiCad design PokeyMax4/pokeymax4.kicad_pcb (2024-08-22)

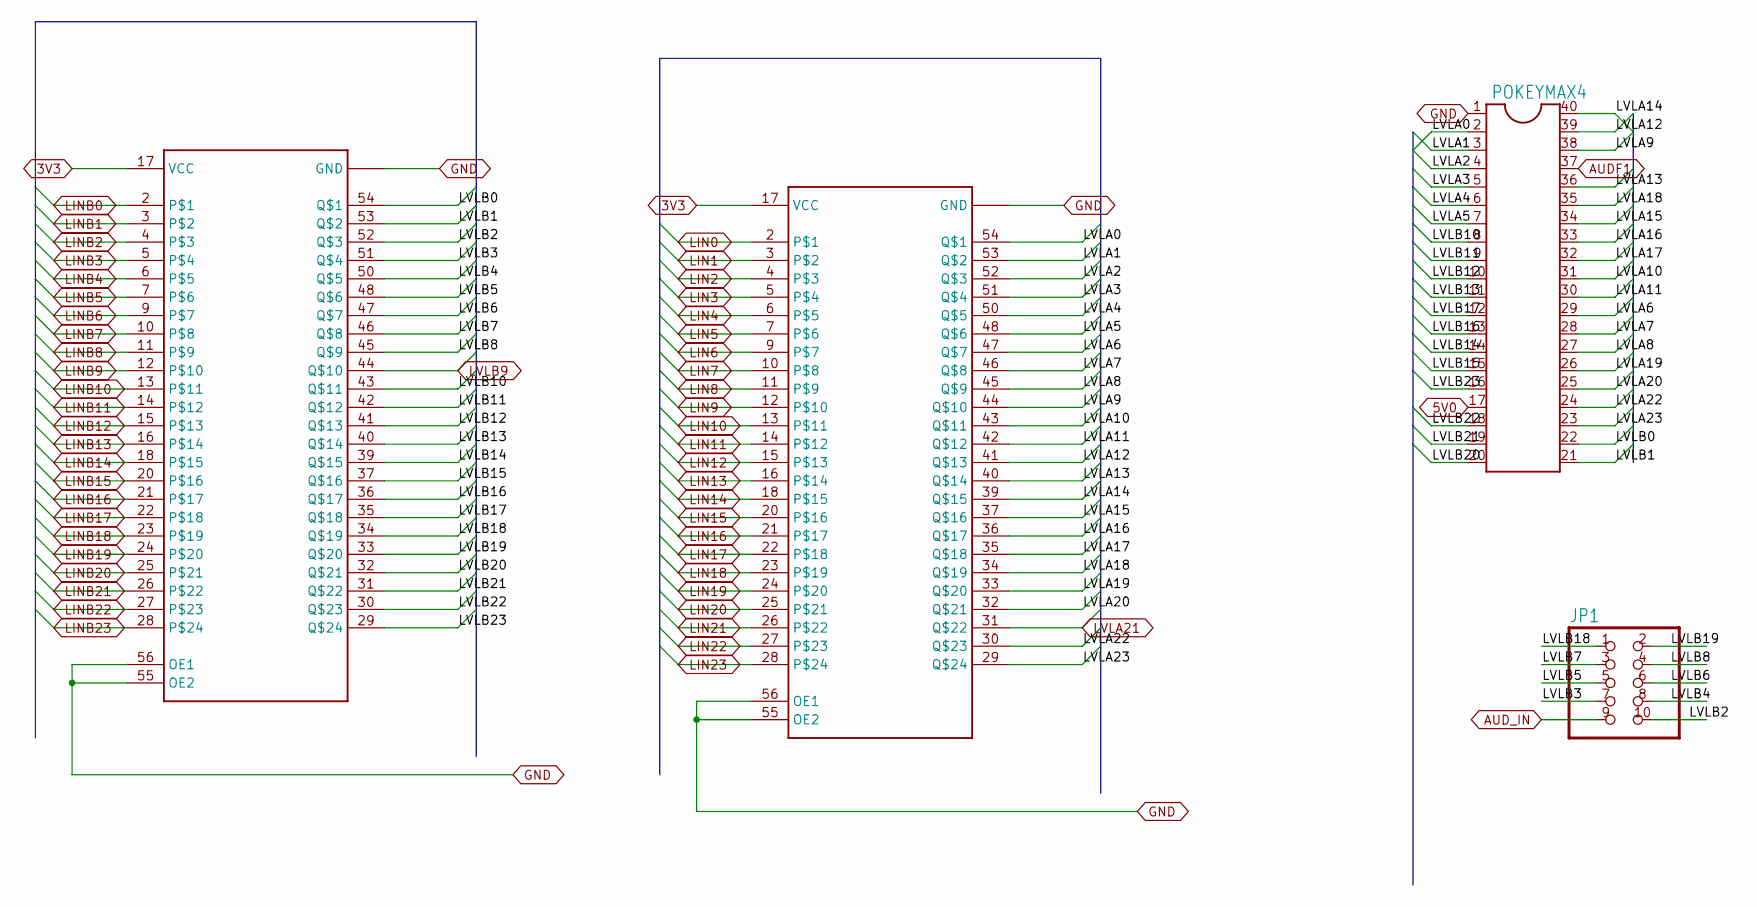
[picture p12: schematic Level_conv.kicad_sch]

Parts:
JP1: PINHD-2X5; 2X05
POKEYMAX4: DIL40
U2, U4: SN74CB3T16211SM; 56TVSOP_SMALL; LCSC Part # C2674751

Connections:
3V3: U2.17 (VCC), U4.17 (VCC); also elsewhere on the board
5V0: POKEYMAX4.17; also elsewhere on the board
/Level conv/LVLA0: POKEYMAX4.2, U2.54
/Level conv/LVLA1: POKEYMAX4.3, U2.53
/Level conv/LVLA2: POKEYMAX4.4, U2.52
/Level conv/LVLA3: POKEYMAX4.5, U2.51
/Level conv/LVLA4: POKEYMAX4.6, U2.50
/Level conv/LVLA5: POKEYMAX4.7, U2.48
/Level conv/LVLA6: POKEYMAX4.29, U2.47
/Level conv/LVLA7: POKEYMAX4.28, U2.46
/Level conv/LVLA8: POKEYMAX4.27, U2.45
/Level conv/LVLA9: POKEYMAX4.38, U2.44
/Level conv/LVLA10: POKEYMAX4.31, U2.43
/Level conv/LVLA11: POKEYMAX4.30, U2.42
/Level conv/LVLA12: POKEYMAX4.39, U2.41
/Level conv/LVLA13: POKEYMAX4.36, U2.40
/Level conv/LVLA14: POKEYMAX4.40, U2.39
/Level conv/LVLA15: POKEYMAX4.34, U2.37
/Level conv/LVLA16: POKEYMAX4.33, U2.36
/Level conv/LVLA17: POKEYMAX4.32, U2.35
/Level conv/LVLA18: POKEYMAX4.35, U2.34
/Level conv/LVLA19: POKEYMAX4.26, U2.33
/Level conv/LVLA20: POKEYMAX4.25, U2.32
/Level conv/LVLA22: POKEYMAX4.24, U2.30
/Level conv/LVLA23: POKEYMAX4.23, U2.29
/Level conv/LVLB0: POKEYMAX4.22, U4.54
/Level conv/LVLB1: POKEYMAX4.21, U4.53
/Level conv/LVLB2: JP1.10, U4.52
/Level conv/LVLB3: JP1.7, U4.51
/Level conv/LVLB4: JP1.8, U4.50
/Level conv/LVLB5: JP1.5, U4.48
/Level conv/LVLB6: JP1.6, U4.47
/Level conv/LVLB7: JP1.3, U4.46
/Level conv/LVLB8: JP1.4, U4.45
/Level conv/LVLB10: POKEYMAX4.8, U4.43
/Level conv/LVLB11: POKEYMAX4.9, U4.42
/Level conv/LVLB12: POKEYMAX4.10, U4.41
/Level conv/LVLB13: POKEYMAX4.11, U4.40
/Level conv/LVLB14: POKEYMAX4.14, U4.39
/Level conv/LVLB15: POKEYMAX4.15, U4.37
/Level conv/LVLB16: POKEYMAX4.13, U4.36
/Level conv/LVLB17: POKEYMAX4.12, U4.35
/Level conv/LVLB18: JP1.1, U4.34
/Level conv/LVLB19: JP1.2, U4.33
/Level conv/LVLB20: POKEYMAX4.20, U4.32
/Level conv/LVLB21: POKEYMAX4.19, U4.31
/Level conv/LVLB22: POKEYMAX4.18, U4.30
/Level conv/LVLB23: POKEYMAX4.16, U4.29
AUDF1: POKEYMAX4.37; also elsewhere on the board
AUD_IN: JP1.9; also elsewhere on the board
GND: POKEYMAX4.1, U2.8 (GND), U2.19 (GND), U2.38 (GND), U2.49 (GND), U2.55 (OE2), U2.56 (OE1), U4.8 (GND), U4.19 (GND), U4.38 (GND), U4.49 (GND), U4.55 (OE2), U4.56 (OE1); also elsewhere on the board
LIN0: U2.2; also elsewhere on the board
LIN1: U2.3; also elsewhere on the board
LIN2: U2.4; also elsewhere on the board
LIN3: U2.5; also elsewhere on the board
LIN4: U2.6; also elsewhere on the board
LIN5: U2.7; also elsewhere on the board
LIN6: U2.9; also elsewhere on the board
LIN7: U2.10; also elsewhere on the board
LIN8: U2.11; also elsewhere on the board
LIN9: U2.12; also elsewhere on the board
LIN10: U2.13; also elsewhere on the board
LIN11: U2.14; also elsewhere on the board
LIN12: U2.15; also elsewhere on the board
LIN13: U2.16; also elsewhere on the board
LIN14: U2.18; also elsewhere on the board
LIN15: U2.20; also elsewhere on the board
LIN16: U2.21; also elsewhere on the board
LIN17: U2.22; also elsewhere on the board
LIN18: U2.23; also elsewhere on the board
LIN19: U2.24; also elsewhere on the board
LIN20: U2.25; also elsewhere on the board
LIN21: U2.26; also elsewhere on the board
LIN22: U2.27; also elsewhere on the board
LIN23: U2.28; also elsewhere on the board
LINB0: U4.2; also elsewhere on the board
LINB1: U4.3; also elsewhere on the board
LINB2: U4.4; also elsewhere on the board
LINB3: U4.5; also elsewhere on the board
LINB4: U4.6; also elsewhere on the board
LINB5: U4.7; also elsewhere on the board
LINB6: U4.9; also elsewhere on the board
LINB7: U4.10; also elsewhere on the board
LINB8: U4.11; also elsewhere on the board
LINB9: U4.12; also elsewhere on the board
LINB10: U4.13; also elsewhere on the board
LINB11: U4.14; also elsewhere on the board
LINB12: U4.15; also elsewhere on the board
LINB13: U4.16; also elsewhere on the board
LINB14: U4.18; also elsewhere on the board
LINB15: U4.20; also elsewhere on the board
LINB16: U4.21; also elsewhere on the board
LINB17: U4.22; also elsewhere on the board
LINB18: U4.23; also elsewhere on the board
LINB19: U4.24; also elsewhere on the board
LINB20: U4.25; also elsewhere on the board
LINB21: U4.26; also elsewhere on the board
LINB22: U4.27; also elsewhere on the board
LINB23: U4.28; also elsewhere on the board
LVLA21: U2.31; also elsewhere on the board
LVLB9: U4.44; also elsewhere on the board

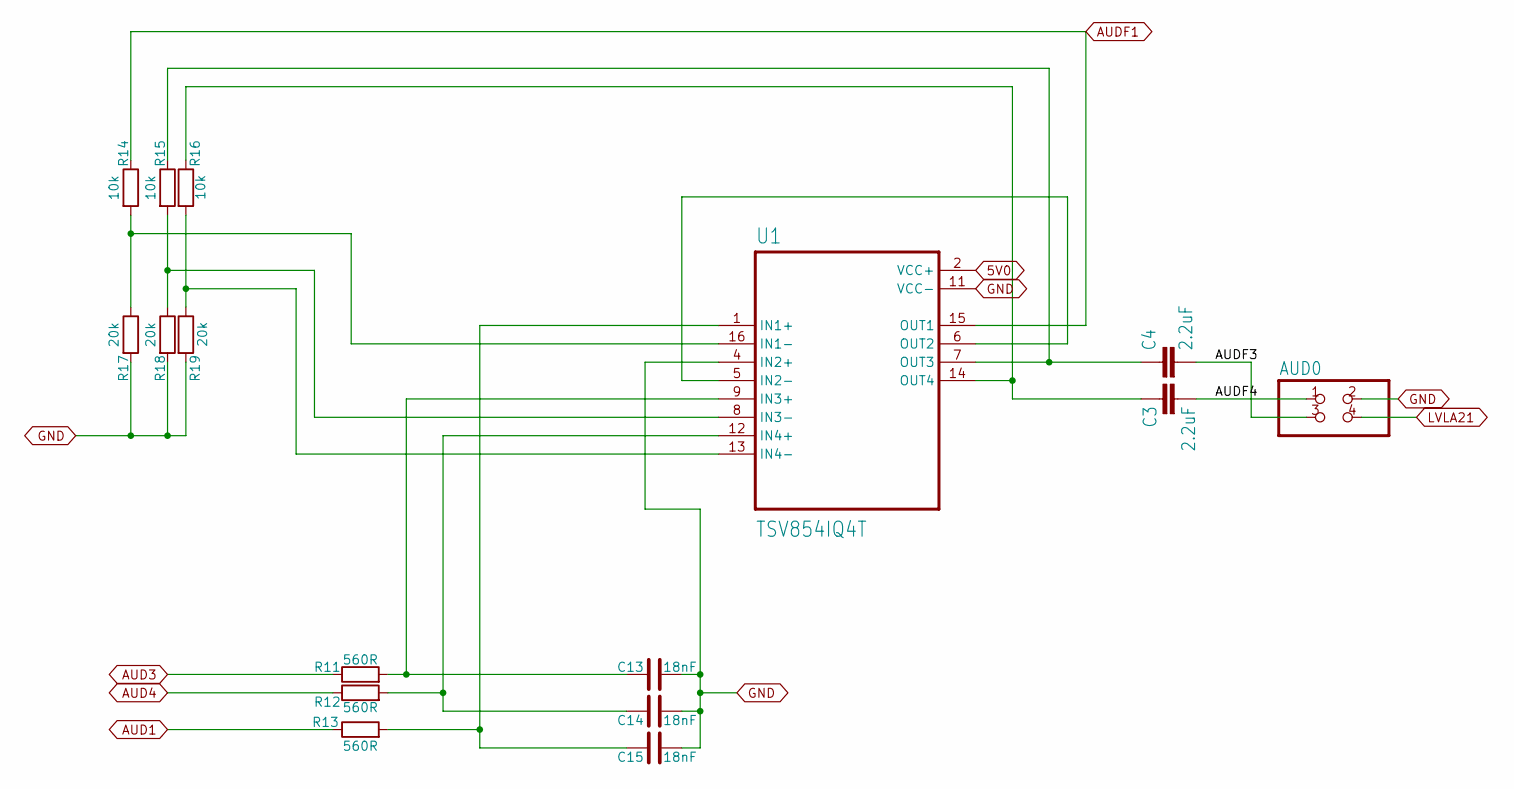
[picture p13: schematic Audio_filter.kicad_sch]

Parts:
AUD0: PINHD-2X2; 2X02
C3, C4: 2.2uF; C0402; LCSC Part # C43922
C13, C14, C15: 18nF; C0402; LCSC Part # C107079
R11, R12, R13: 560R; R_0402_1005Metric
R14, R15, R16: 10k; R_0402_1005Metric
R17, R18, R19: 20k; R_0402_1005Metric
U1: TSV854IQ4T; QFN50P300X300X100-16N; LCSC Part # C2058240

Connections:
5V0: U1.2 (VCC+); also elsewhere on the board
/Audio filter/AUDF3: AUD0.3, C4.2
/Audio filter/AUDF4: AUD0.1, C3.2
AUD1: R13.1; also elsewhere on the board
AUD3: R11.1; also elsewhere on the board
AUD4: R12.1; also elsewhere on the board
AUDF1: R14.1, U1.15 (OUT1); also elsewhere on the board
GND: AUD0.2, C13.2, C14.2, C15.2, R17.2, R18.2, R19.2, U1.4 (IN2+), U1.11 (VCC-); also elsewhere on the board
LVLA21: AUD0.4; also elsewhere on the board
unnamed: C15.1, R13.2, U1.1 (IN1+)
unnamed: R14.2, R17.1, U1.16 (IN1-)
unnamed: U1.5 (IN2-), U1.6 (OUT2)
unnamed: C13.1, R11.2, U1.9 (IN3+)
unnamed: R15.2, R18.1, U1.8 (IN3-)
unnamed: C14.1, R12.2, U1.12 (IN4+)
unnamed: R16.2, R19.1, U1.13 (IN4-)
unnamed: C4.1, R15.1, U1.7 (OUT3)
unnamed: C3.1, R16.1, U1.14 (OUT4)

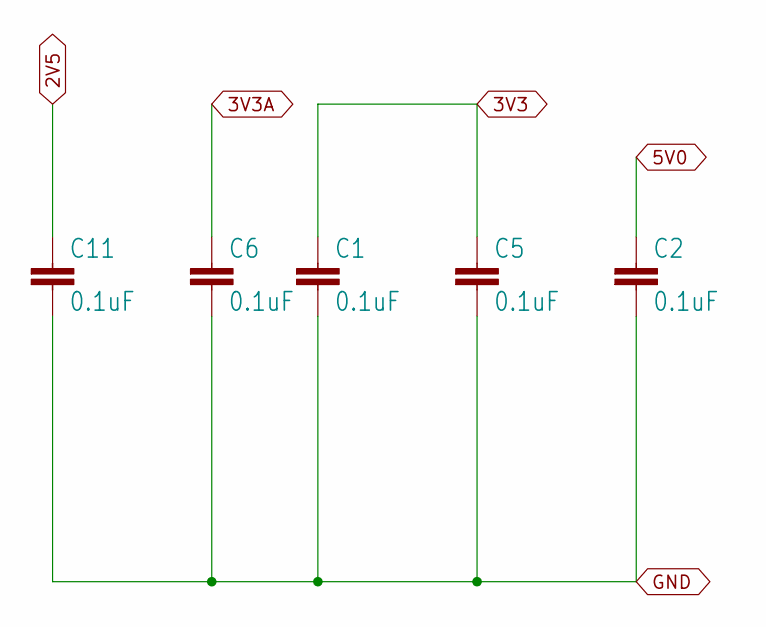
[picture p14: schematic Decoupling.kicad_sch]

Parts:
C1, C2, C5, C6, C11: 0.1uF; C0402; LCSC Part # C88219

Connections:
2V5: C11.1; also elsewhere on the board
3V3: C1.1, C5.1; also elsewhere on the board
3V3A: C6.1; also elsewhere on the board
5V0: C2.1; also elsewhere on the board
GND: C1.2, C2.2, C5.2, C6.2, C11.2; also elsewhere on the board

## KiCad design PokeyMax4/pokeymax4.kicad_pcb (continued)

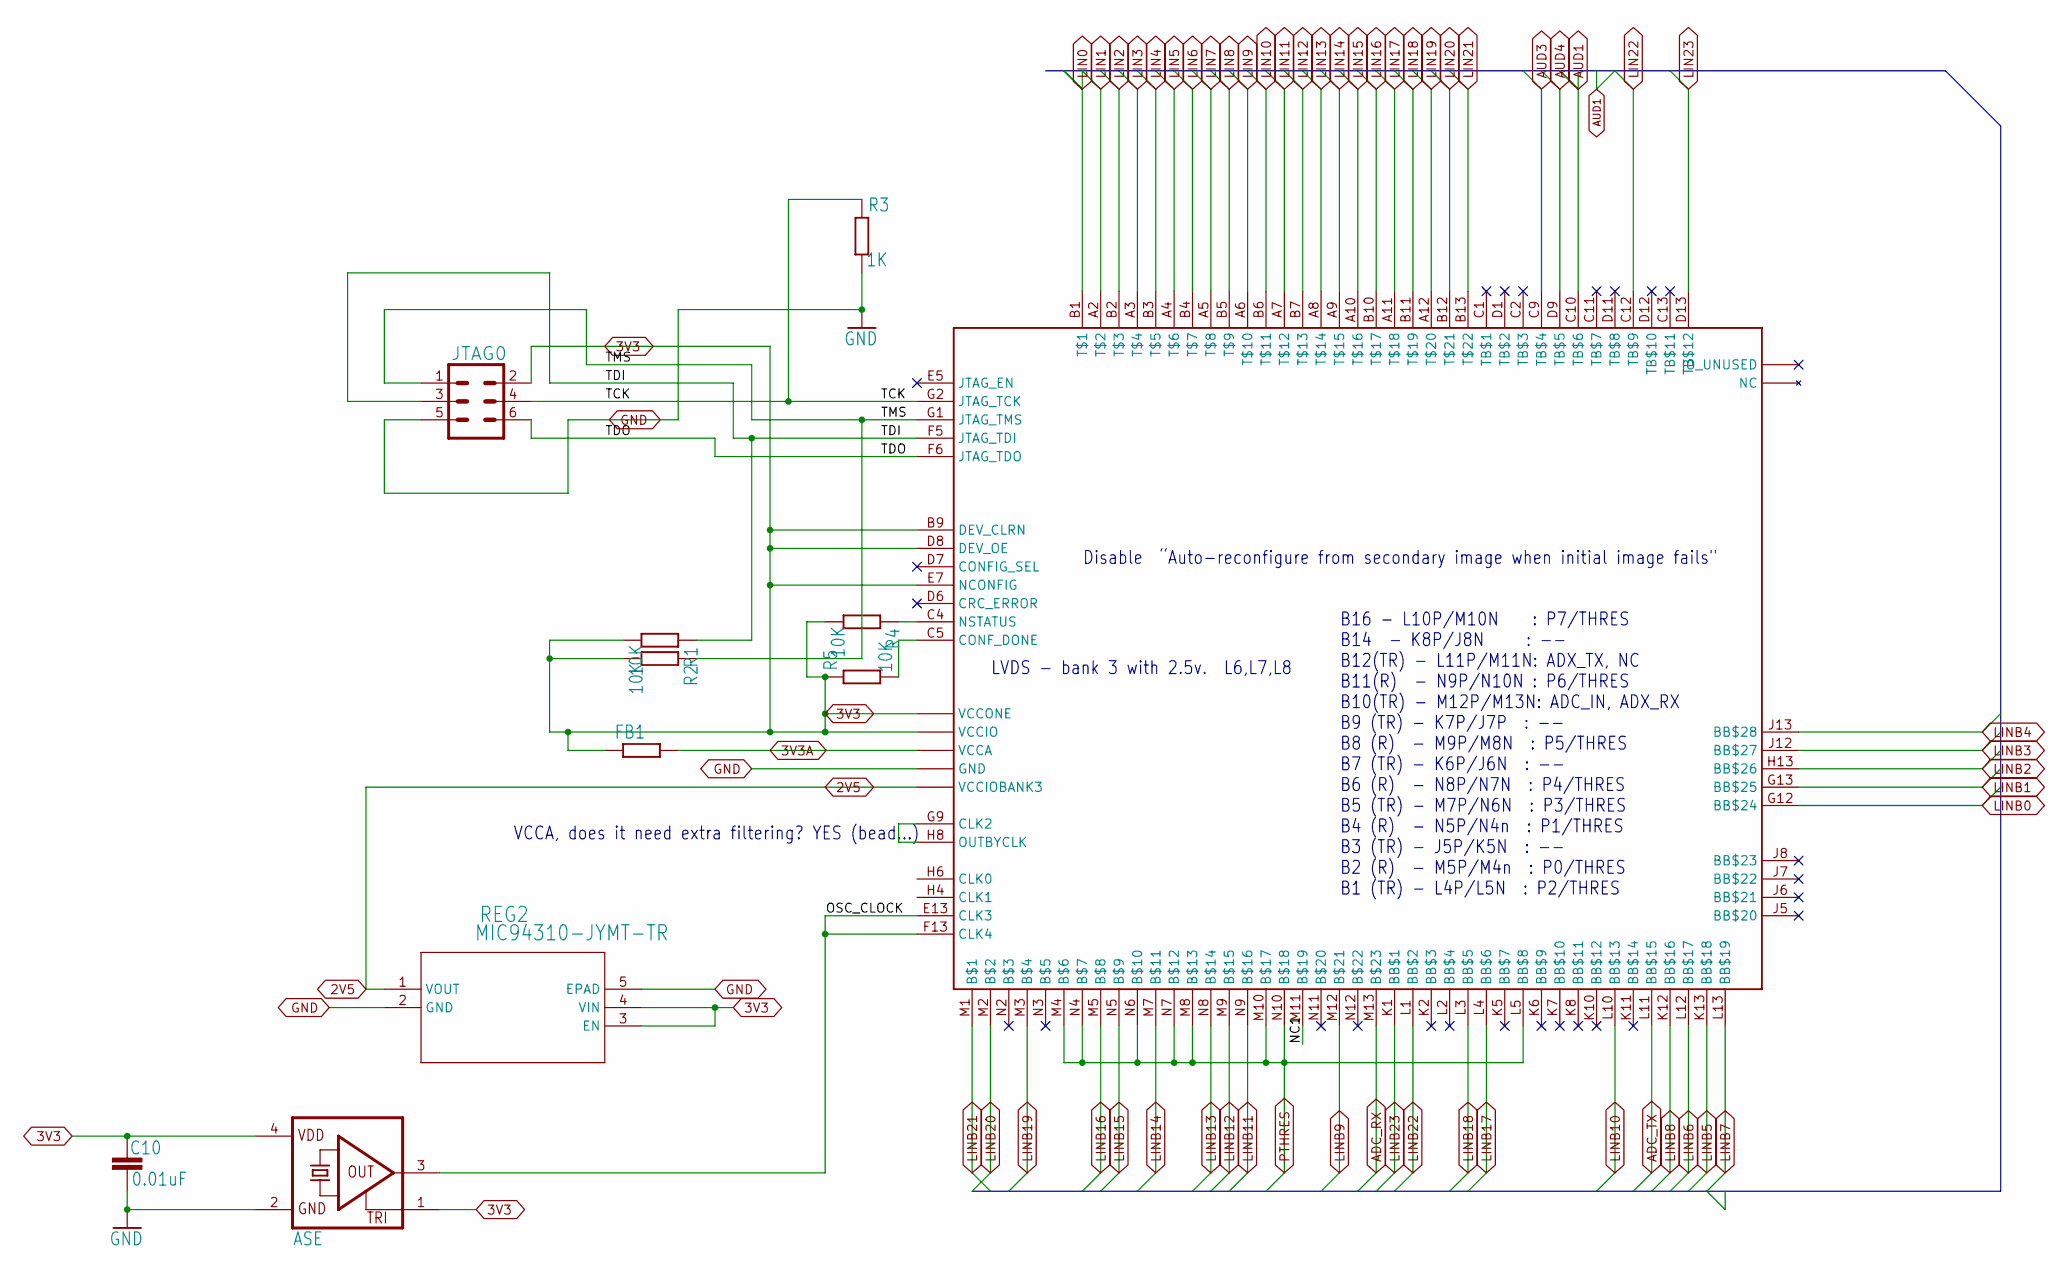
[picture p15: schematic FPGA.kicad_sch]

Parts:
C10: 0.01uF; C0402; LCSC Part # C43253
FB1: R-EU_R0402; R0402; LCSC Part # C710330
JTAG0: CONN_03X2LOCK; 2X3_LOCK
R1, R2, R4, R5: 10K; R0402; LCSC Part # C103199
R3: 1K; R0402; LCSC Part # C107079
REG2: MIC94310-JYMT-TR; TDFN4_1P2X1P6_MCH; LCSC Part # C622559
U3: MAX10; U169SMALL; LCSC Part # C1521935
X1: ASE; LCSC Part # C7431354

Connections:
2V5: REG2.1 (VOUT), U3.L6 (VCCIOBANK3), U3.L7 (VCCIOBANK3), U3.L8 (VCCIOBANK3); also elsewhere on the board
3V3: C10.1, FB1.1, JTAG0.2, R1.2, R2.2, R4.2, R5.1, REG2.3 (EN), REG2.4 (VIN), U3.B9 (DEV_CLRN), U3.C6 (VCCIO), U3.C7 (VCCIO), U3.C8 (VCCIO), U3.D8 (DEV_OE), U3.E7 (NCONFIG), U3.F2 (VCCIO), U3.F7 (VCCONE), U3.F11 (VCCIO), U3.G3 (VCCIO), U3.G6 (VCCONE), U3.G8 (VCCONE), U3.G11 (VCCIO), U3.H7 (VCCONE), U3.H11 (VCCIO), U3.J3 (VCCIO), U3.J11 (VCCIO), U3.K3 (VCCIO), X1.1 (TRI), X1.4 (VDD); also elsewhere on the board
3V3A: FB1.2, U3.D4 (VCCA), U3.D10 (VCCA), U3.K4 (VCCA), U3.K9 (VCCA); also elsewhere on the board
/FPGA/NC1: U3.M11
/FPGA/OSC_CLOCK: U3.E13 (CLK3), U3.F13 (CLK4), X1.3 (OUT)
/FPGA/TCK: JTAG0.4, R3.1, U3.G2 (JTAG_TCK)
/FPGA/TDI: JTAG0.3, R1.1, U3.F5 (JTAG_TDI)
/FPGA/TDO: JTAG0.6, U3.F6 (JTAG_TDO)
/FPGA/TMS: JTAG0.1, R2.1, U3.G1 (JTAG_TMS)
ADC_RX: U3.M13; also elsewhere on the board
ADC_TX: U3.L11 (BB$15); also elsewhere on the board
AUD1: U3.C10 (TB$6); also elsewhere on the board
AUD3: U3.C9 (TB$4); also elsewhere on the board
AUD4: U3.D9 (TB$5); also elsewhere on the board
GND: C10.2, JTAG0.5, R3.2, REG2.2 (GND), REG2.5 (EPAD), U3.A1 (GND), U3.A13 (GND), U3.B8 (GND), U3.C3 (GND), U3.D5 (GND), U3.E11 (GND), U3.F3 (GND), U3.G7 (GND), U3.H12 (GND), U3.J4 (GND), U3.L9 (GND), U3.M6 (GND), U3.N1 (GND), U3.N13 (GND), X1.2 (GND); also elsewhere on the board
LIN0: U3.B1; also elsewhere on the board
LIN1: U3.A2; also elsewhere on the board
LIN2: U3.B2; also elsewhere on the board
LIN3: U3.A3; also elsewhere on the board
LIN4: U3.B3; also elsewhere on the board
LIN5: U3.A4; also elsewhere on the board
LIN6: U3.B4; also elsewhere on the board
LIN7: U3.A5; also elsewhere on the board
LIN8: U3.B5; also elsewhere on the board
LIN9: U3.A6; also elsewhere on the board
LIN10: U3.B6; also elsewhere on the board
LIN11: U3.A7; also elsewhere on the board
LIN12: U3.B7; also elsewhere on the board
LIN13: U3.A8; also elsewhere on the board
LIN14: U3.A9; also elsewhere on the board
LIN15: U3.A10; also elsewhere on the board
LIN16: U3.B10; also elsewhere on the board
LIN17: U3.A11; also elsewhere on the board
LIN18: U3.B11; also elsewhere on the board
LIN19: U3.A12; also elsewhere on the board
LIN20: U3.B12; also elsewhere on the board
LIN21: U3.B13; also elsewhere on the board
LIN22: U3.C12 (TB$9); also elsewhere on the board
LIN23: U3.D13 (TB$12); also elsewhere on the board
LINB0: U3.G12 (BB$24); also elsewhere on the board
LINB1: U3.G13 (BB$25); also elsewhere on the board
LINB2: U3.H13 (BB$26); also elsewhere on the board
LINB3: U3.J12 (BB$27); also elsewhere on the board
LINB4: U3.J13 (BB$28); also elsewhere on the board
LINB5: U3.K13 (BB$18); also elsewhere on the board
LINB6: U3.L12 (BB$17); also elsewhere on the board
LINB7: U3.L13 (BB$19); also elsewhere on the board
LINB8: U3.K12 (BB$16); also elsewhere on the board
LINB9: U3.M12; also elsewhere on the board
LINB10: U3.L10 (BB$13); also elsewhere on the board
LINB11: U3.N9; also elsewhere on the board
LINB12: U3.M9; also elsewhere on the board
LINB13: U3.N8; also elsewhere on the board
LINB14: U3.M7; also elsewhere on the board
LINB15: U3.N5; also elsewhere on the board
LINB16: U3.M5; also elsewhere on the board
LINB17: U3.L4 (BB$6); also elsewhere on the board
LINB18: U3.L3 (BB$5); also elsewhere on the board
LINB19: U3.M3; also elsewhere on the board
LINB20: U3.M2; also elsewhere on the board
LINB21: U3.M1; also elsewhere on the board
LINB22: U3.L1 (BB$2); also elsewhere on the board
LINB23: U3.K1 (BB$1); also elsewhere on the board
unnamed: U3.G9 (CLK2), U3.H8 (OUTBYCLK)
unnamed: R5.2, U3.C5 (CONF_DONE)
unnamed: R4.1, U3.C4 (NSTATUS)
PTHRES: U3.L5 (BB$8), U3.M4, U3.M8, U3.M10, U3.N4, U3.N6, U3.N7, U3.N10; also elsewhere on the board

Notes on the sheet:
Disable “Auto-reconfigure from secondary image when initial image fails"
B16 - L10P/M10N : P7/THRES B14 - K8P/J8N : -- B12(TR) - L11P/M11N: ADX_TX, NC B11(R) - N9P/N10N : P6/THRES B10(TR) - M12P/M13N: ADC_IN, ADX_RX B9 (TR) - K7P/J7P : -- B8 (R) - M9P/M8N : P5/THRES B7 (TR) - K6P/J6N : -- B6 (R) - N8P/N7N : P4/THRES B5 (TR) - M7P/N6N : P3/THRES B4 (R) - N5P/N4n : P1/THR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
LVDS - bank 3 with 2.5v. L6,L7,L8
VCCA, does it need extra filtering? YES (bead...)


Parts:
C8: 2.2uF; C0402; LCSC Part # C43922
C9: 4.7uF; C0402; LCSC Part # C112433
L1: LQM2HPN1R0MJ0L; INDC1008X04; LCSC Part # C216157
REG1: TPS62237DRYR; DRY6; LCSC Part # C398923

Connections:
3V3: C9.1, L1.2, REG1.6 (FB); also elsewhere on the board
5V0: C8.1, REG1.3 (VIN), REG1.5 (EN); also elsewhere on the board
GND: C8.2, C9.2, REG1.1 (MODE), REG1.4 (GND); also elsewhere on the board
unnamed: L1.1, REG1.2 (SW)


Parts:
C7: 1nF; C0402; LCSC Part # C1636
C12: 2.2uF; C0402; LCSC Part # C43922
R8, R9: 3k3; R0402; LCSC Part # C72816
R10: 1k1; R0402; LCSC Part # C140120

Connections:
2V5: R9.2; also elsewhere on the board
ADC_RX: C7.1, R10.2; also elsewhere on the board
ADC_TX: R10.1; also elsewhere on the board
AUD_IN: C12.2; also elsewhere on the board
GND: C7.2, R8.1; also elsewhere on the board
LVLB9: C12.1, R8.2, R9.1; also elsewhere on the board

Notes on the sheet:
ADC IN BIAS
FPGA ADC support


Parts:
R6: 1k1; R0402; LCSC Part # C140120
R7: 2k2; R0402; LCSC Part # C294652

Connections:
3V3: R6.2; also elsewhere on the board
GND: R7.1; also elsewhere on the board
PTHRES: R6.1, R7.2; also elsewhere on the board


Board: 2 copper layers, 20.7 x 52.8 mm, 47 parts (0 on the bottom side), 129 nets.

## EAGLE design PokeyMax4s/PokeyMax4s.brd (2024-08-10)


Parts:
R6: 1k1; R0402
R7: 2k2; R0402

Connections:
3V3: R6.2; also elsewhere on the board
GND: R7.1; also elsewhere on the board
PTHRES: R6.1, R7.2; also elsewhere on the board


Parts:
C10: 0.01uF; C0402
FB1: R-EU_R0402; R0402
JTAG: CONN_03X2LOCK; 2X3_LOCK
R1, R2, R4, R5: 10K; R0402
R3: 1K; R0402
REG2: MIC94310-JYMT-TR; TDFN4_1P2X1P6_MCH
U3: MAX10; U169SMALL
X1: ASE

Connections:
2V5: REG2.1 (VOUT), U3.L6 (VCCIOBANK3), U3.L7 (VCCIOBANK3), U3.L8 (VCCIOBANK3); also elsewhere on the board
3V3: C10.1, FB1.1, JTAG.2, R1.2, R2.2, R4.2, R5.1, REG2.3 (EN), REG2.4 (VIN), U3.B9 (DEV_CLRN), U3.C6 (VCCIO), U3.C7 (VCCIO), U3.C8 (VCCIO), U3.D8 (DEV_OE), U3.E7 (NCONFIG), U3.F2 (VCCIO), U3.F7 (VCCONE), U3.F11 (VCCIO), U3.G3 (VCCIO), U3.G6 (VCCONE), U3.G8 (VCCONE), U3.G11 (VCCIO), U3.H7 (VCCONE), U3.H11 (VCCIO), U3.J3 (VCCIO), U3.J11 (VCCIO), U3.K3 (VCCIO), X1.1 (TRI), X1.4 (VDD); also elsewhere on the board
3V3A: FB1.2, U3.D4 (VCCA), U3.D10 (VCCA), U3.K4 (VCCA), U3.K9 (VCCA); also elsewhere on the board
ADC_RX: U3.M13; also elsewhere on the board
ADC_TX: U3.L11 (BB$15); also elsewhere on the board
AUD1: U3.C10 (TB$6); also elsewhere on the board
AUD3: U3.C9 (TB$4); also elsewhere on the board
AUD4: U3.D9 (TB$5); also elsewhere on the board
CONF_DONE: R5.2, U3.C5 (CONF_DONE)
FAKE_CLK: U3.G9 (CLK2), U3.H8 (OUTBYCLK)
GND: C10.2, JTAG.5, R3.2, REG2.2 (GND), REG2.5 (EPAD), U3.A1 (GND), U3.A13 (GND), U3.B8 (GND), U3.C3 (GND), U3.D5 (GND), U3.E11 (GND), U3.F3 (GND), U3.G7 (GND), U3.H12 (GND), U3.J4 (GND), U3.L9 (GND), U3.M6 (GND), U3.N1 (GND), U3.N13 (GND), X1.2 (GND); also elsewhere on the board
LIN0: U3.B1; also elsewhere on the board
LIN1: U3.A2; also elsewhere on the board
LIN2: U3.B2; also elsewhere on the board
LIN3: U3.A3; also elsewhere on the board
LIN4: U3.B3; also elsewhere on the board
LIN5: U3.A4; also elsewhere on the board
LIN6: U3.B4; also elsewhere on the board
LIN7: U3.A5; also elsewhere on the board
LIN8: U3.B5; also elsewhere on the board
LIN9: U3.A6; also elsewhere on the board
LIN10: U3.B6; also elsewhere on the board
LIN11: U3.A7; also elsewhere on the board
LIN12: U3.B7; also elsewhere on the board
LIN13: U3.A8; also elsewhere on the board
LIN14: U3.A9; also elsewhere on the board
LIN15: U3.A10; also elsewhere on the board
LIN16: U3.B10; also elsewhere on the board
LIN17: U3.A11; also elsewhere on the board
LIN18: U3.B11; also elsewhere on the board
LIN19: U3.A12; also elsewhere on the board
LIN20: U3.B12; also elsewhere on the board
LIN21: U3.B13; also elsewhere on the board
LIN22: U3.C12 (TB$9); also elsewhere on the board
LIN23: U3.D13 (TB$12); also elsewhere on the board
LINB0: U3.G12 (BB$24); also elsewhere on the board
LINB1: U3.G13 (BB$25); also elsewhere on the board
LINB2: U3.H13 (BB$26); also elsewhere on the board
LINB3: U3.J12 (BB$27); also elsewhere on the board
LINB4: U3.J13 (BB$28); also elsewhere on the board
LINB5: U3.K13 (BB$18); also elsewhere on the board
LINB6: U3.L12 (BB$17); also elsewhere on the board
LINB7: U3.L13 (BB$19); also elsewhere on the board
LINB8: U3.K12 (BB$16); also elsewhere on the board
LINB9: U3.M12; also elsewhere on the board
LINB10: U3.L10 (BB$13); also elsewhere on the board
LINB11: U3.N9; also elsewhere on the board
LINB12: U3.M9; also elsewhere on the board
LINB13: U3.N8; also elsewhere on the board
LINB14: U3.M7; also elsewhere on the board
LINB15: U3.N5; also elsewhere on the board
LINB16: U3.M5; also elsewhere on the board
LINB17: U3.L4 (BB$6); also elsewhere on the board
LINB18: U3.L3 (BB$5); also elsewhere on the board
LINB19: U3.M3; also elsewhere on the board
LINB20: U3.M2; also elsewhere on the board
LINB21: U3.M1; also elsewhere on the board
LINB22: U3.L1 (BB$2); also elsewhere on the board
LINB23: U3.K1 (BB$1); also elsewhere on the board
NC1: U3.M11
NSTATUS: R4.1, U3.C4 (NSTATUS)
OSC_CLOCK: U3.E13 (CLK3), U3.F13 (CLK4), X1.3 (OUT)
PTHRES: U3.L5 (BB$8), U3.M4, U3.M8, U3.M10, U3.N4, U3.N6, U3.N7, U3.N10; also elsewhere on the board
TCK: JTAG.4, R3.1, U3.G2 (JTAG_TCK)
TDI: JTAG.3, R1.1, U3.F5 (JTAG_TDI)
TDO: JTAG.6, U3.F6 (JTAG_TDO)
TMS: JTAG.1, R2.1, U3.G1 (JTAG_TMS)

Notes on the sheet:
VCCA, does it need extra filtering? YES (bead...)
Disable “Auto-reconfigure from secondary image when initial image fails"
LVDS - bank 3 with 2.5v. L6,L7,L8
B16 - L10P/M10N : P7/THRES B14 - K8P/J8N : -- B12(TR) - L11P/M11N: ADX_TX, NC B11(R) - N9P/N10N : P6/THRES B10(TR) - M12P/M13N: ADC_IN, ADX_RX B9 (TR) - K7P/J7P : -- B8 (R) - M9P/M8N : P5/THRES B7 (TR) - K6P/J6N : -- B6 (R) - N8P/N7N : P4/THRES B5 (TR) - M7P/N6N : P3/THRES B4 (R) - N5P/N4n : P1/THR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


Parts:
JP1: PINHD-2X5; 2X05
POKEYMAX4: DIL40
U2, U4: SN74CB3T16211SM; 56TVSOP_SMALL

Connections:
3V3: U2.17 (VCC), U4.17 (VCC); also elsewhere on the board
5V0: POKEYMAX4.17; also elsewhere on the board
AUDF1: POKEYMAX4.37; also elsewhere on the board
AUD_IN: JP1.9; also elsewhere on the board
GND: POKEYMAX4.1, U2.8 (GND), U2.19 (GND), U2.38 (GND), U2.49 (GND), U2.55 (OE2), U2.56 (OE1), U4.8 (GND), U4.19 (GND), U4.38 (GND), U4.49 (GND), U4.55 (OE2), U4.56 (OE1); also elsewhere on the board
LIN0: U2.2; also elsewhere on the board
LIN1: U2.3; also elsewhere on the board
LIN2: U2.4; also elsewhere on the board
LIN3: U2.5; also elsewhere on the board
LIN4: U2.6; also elsewhere on the board
LIN5: U2.7; also elsewhere on the board
LIN6: U2.9; also elsewhere on the board
LIN7: U2.10; also elsewhere on the board
LIN8: U2.11; also elsewhere on the board
LIN9: U2.12; also elsewhere on the board
LIN10: U2.13; also elsewhere on the board
LIN11: U2.14; also elsewhere on the board
LIN12: U2.15; also elsewhere on the board
LIN13: U2.16; also elsewhere on the board
LIN14: U2.18; also elsewhere on the board
LIN15: U2.20; also elsewhere on the board
LIN16: U2.21; also elsewhere on the board
LIN17: U2.22; also elsewhere on the board
LIN18: U2.23; also elsewhere on the board
LIN19: U2.24; also elsewhere on the board
LIN20: U2.25; also elsewhere on the board
LIN21: U2.26; also elsewhere on the board
LIN22: U2.27; also elsewhere on the board
LIN23: U2.28; also elsewhere on the board
LINB0: U4.2; also elsewhere on the board
LINB1: U4.3; also elsewhere on the board
LINB2: U4.4; also elsewhere on the board
LINB3: U4.5; also elsewhere on the board
LINB4: U4.6; also elsewhere on the board
LINB5: U4.7; also elsewhere on the board
LINB6: U4.9; also elsewhere on the board
LINB7: U4.10; also elsewhere on the board
LINB8: U4.11; also elsewhere on the board
LINB9: U4.12; also elsewhere on the board
LINB10: U4.13; also elsewhere on the board
LINB11: U4.14; also elsewhere on the board
LINB12: U4.15; also elsewhere on the board
LINB13: U4.16; also elsewhere on the board
LINB14: U4.18; also elsewhere on the board
LINB15: U4.20; also elsewhere on the board
LINB16: U4.21; also elsewhere on the board
LINB17: U4.22; also elsewhere on the board
LINB18: U4.23; also elsewhere on the board
LINB19: U4.24; also elsewhere on the board
LINB20: U4.25; also elsewhere on the board
LINB21: U4.26; also elsewhere on the board
LINB22: U4.27; also elsewhere on the board
LINB23: U4.28; also elsewhere on the board
LVLA0: POKEYMAX4.2, U2.54
LVLA1: POKEYMAX4.3, U2.53
LVLA2: POKEYMAX4.4, U2.52
LVLA3: POKEYMAX4.5, U2.51
LVLA4: POKEYMAX4.6, U2.50
LVLA5: POKEYMAX4.7, U2.48
LVLA6: POKEYMAX4.29, U2.47
LVLA7: POKEYMAX4.28, U2.46
LVLA8: POKEYMAX4.27, U2.45
LVLA9: POKEYMAX4.38, U2.44
LVLA10: POKEYMAX4.31, U2.43
LVLA11: POKEYMAX4.30, U2.42
LVLA12: POKEYMAX4.39, U2.41
LVLA13: POKEYMAX4.36, U2.40
LVLA14: POKEYMAX4.40, U2.39
LVLA15: POKEYMAX4.34, U2.37
LVLA16: POKEYMAX4.33, U2.36
LVLA17: POKEYMAX4.32, U2.35
LVLA18: POKEYMAX4.35, U2.34
LVLA19: POKEYMAX4.26, U2.33
LVLA20: POKEYMAX4.25, U2.32
LVLA21: U2.31; also elsewhere on the board
LVLA22: POKEYMAX4.24, U2.30
LVLA23: POKEYMAX4.23, U2.29
LVLB0: POKEYMAX4.22, U4.54
LVLB1: POKEYMAX4.21, U4.53
LVLB2: JP1.10, U4.52
LVLB3: JP1.7, U4.51
LVLB4: JP1.8, U4.50
LVLB5: JP1.5, U4.48
LVLB6: JP1.6, U4.47
LVLB7: JP1.3, U4.46
LVLB8: JP1.4, U4.45
LVLB9: U4.44; also elsewhere on the board
LVLB10: POKEYMAX4.8, U4.43
LVLB11: POKEYMAX4.9, U4.42
LVLB12: POKEYMAX4.10, U4.41
LVLB13: POKEYMAX4.11, U4.40
LVLB14: POKEYMAX4.14, U4.39
LVLB15: POKEYMAX4.15, U4.37
LVLB16: POKEYMAX4.13, U4.36
LVLB17: POKEYMAX4.12, U4.35
LVLB18: JP1.1, U4.34
LVLB19: JP1.2, U4.33
LVLB20: POKEYMAX4.20, U4.32
LVLB21: POKEYMAX4.19, U4.31
LVLB22: POKEYMAX4.18, U4.30
LVLB23: POKEYMAX4.16, U4.29


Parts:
C8: 2.2uF; C0402
C9: 4.7uF; C0402
L1: LQM2HPN1R0MJ0L; INDC1008X04
REG1: TPS62237DRYR; DRY6

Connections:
3V3: C9.1, L1.2, REG1.6 (FB); also elsewhere on the board
5V0: C8.1, REG1.3 (VIN), REG1.5 (EN); also elsewhere on the board
GND: C8.2, C9.2, REG1.1 (MODE), REG1.4 (GND); also elsewhere on the board
unnamed: L1.1, REG1.2 (SW)


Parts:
AUD: PINHD-2X2; 2X02
C3, C4: 2.2uF; C0402
CN1: 18nF; R1206-8
RN1: 20K; 741-8
RN2: 10K; 741-8
RN3: 560; 741-8
U1: TSV854IQ4T; QFN50P300X300X100-16N

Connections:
5V0: U1.2 (VCC+); also elsewhere on the board
AMPIN1M: RN1.8, RN2.1, U1.16 (IN1-)
AMPIN1P: CN1.8 (2), RN3.1, U1.1 (IN1+)
AMPIN3M: RN1.6, RN2.3, U1.8 (IN3-)
AMPIN3P: CN1.5 (2), RN3.4, U1.9 (IN3+)
AMPIN4P: CN1.6 (2), RN3.3, U1.12 (IN4+)
AUD1: RN3.8; also elsewhere on the board
AUD3: RN3.5; also elsewhere on the board
AUD4: RN3.6; also elsewhere on the board
AUDF1: RN2.8, U1.15 (OUT1); also elsewhere on the board
AUDF2: U1.5 (IN2-), U1.6 (OUT2)
AUDF3: AUD.3, C4.2
AUDF4: AUD.1, C3.2
GND: AUD.2, CN1.1, CN1.2 (1), CN1.3 (1), CN1.4 (1), RN1.1, RN1.2, RN1.3, RN1.4, U1.4 (IN2+), U1.11 (VCC-); also elsewhere on the board
LVLA21: AUD.4; also elsewhere on the board
unnamed: C3.1, RN2.5, U1.14 (OUT4)
unnamed: C4.1, RN2.6, U1.7 (OUT3)
unnamed: RN1.5, RN2.4, U1.13 (IN4-)


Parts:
C1, C2, C5, C6, C11: 0.1uF; C0402

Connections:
2V5: C11.1; also elsewhere on the board
3V3: C1.1, C5.1; also elsewhere on the board
3V3A: C6.1; also elsewhere on the board
5V0: C2.1; also elsewhere on the board
GND: C1.2, C2.2, C5.2, C6.2, C11.2; also elsewhere on the board


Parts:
C7: 1nF; C0402
C12: 2.2uF; C0402
R8, R9: 3k3; R0402
R10: 1k1; R0402

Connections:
2V5: R9.2; also elsewhere on the board
ADC_RX: C7.1, R10.2; also elsewhere on the board
ADC_TX: R10.1; also elsewhere on the board
AUD_IN: C12.2; also elsewhere on the board
GND: C7.2, R8.1; also elsewhere on the board
LVLB9: C12.1, R8.2, R9.1; also elsewhere on the board

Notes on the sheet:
ADC IN BIAS
FPGA ADC support


Board: 2 copper layers, 20.7 x 52.8 mm, 39 parts (0 on the bottom side), 129 nets.

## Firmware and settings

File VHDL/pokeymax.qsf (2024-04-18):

# -------------------------------------------------------------------------- #
#
# Copyright (C) 2017  Intel Corporation. All rights reserved.
# Your use of Intel Corporation's design tools, logic functions 
# and other software and tools, and its AMPP partner logic 
# functions, and any output files from any of the foregoing 
# (including device programming or simulation files), and any 
# associated documentation or information are expressly subject 
# to the terms and conditions of the Intel Program License 
# Subscription Agreement, the Intel Quartus Prime License Agreement,
# the Intel MegaCore Function License Agreement, or other 
# applicable license agreement, including, without limitation, 
# that your use is for the sole purpose of programming logic 
# devices manufactured by Intel and sold by Intel or its 
# authorized distributors.  Please refer to the applicable 
# agreement for further details.
#
# -------------------------------------------------------------------------- #
#
# Quartus Prime
# Version 17.0.0 Build 595 04/25/2017 SJ Lite Edition
# Date created = 19:35:48  June 01, 2018
#
# -------------------------------------------------------------------------- #
#
# Notes:
#
# 1) The default values for assignments are stored in the file:
#		pokeymax_assignment_defaults.qdf
#    If this file doesn't exist, see file:
#		assignment_defaults.qdf
#
# 2) Altera recommends that you do not modify this file. This
#    file is updated automatically by the Quartus Prime software
#    and any changes you make may be lost or overwritten.
#
# -------------------------------------------------------------------------- #


set_global_assignment -name FAMILY "MAX 10"
set_global_assignment -name TOP_LEVEL_ENTITY pokeymax
set_global_assignment -name ORIGINAL_QUARTUS_VERSION 17.0.0
set_global_assignment -name PROJECT_CREATION_TIME_DATE "19:35:48  JUNE 01, 2018"
set_global_assignment -name LAST_QUARTUS_VERSION "19.1.0 Lite Edition"
set_global_assignment -name PROJECT_OUTPUT_DIRECTORY output_files
set_global_assignment -name MIN_CORE_JUNCTION_TEMP 0
set_global_assignment -name MAX_CORE_JUNCTION_TEMP 85
set_global_assignment -name DEVICE_FILTER_PACKAGE UFBGA
set_global_assignment -name DEVICE_FILTER_PIN_COUNT 169
set_global_assignment -name DEVICE_FILTER_SPEED_GRADE 8
set_global_assignment -name ERROR_CHECK_FREQUENCY_DIVISOR 256
set_location_assignment PIN_B1 -to PHI2    #B1,LIN0,LVL8,PHI
set_location_assignment PIN_A2 -to D[7]   #A2,LIN1,LVL7,D7
set_location_assignment PIN_B2 -to D[6]   #B2,LIN2,LVL6,D6
set_location_assignment PIN_A3 -to D[5]   #A3,LIN3,LVL5,D5
set_location_assignment PIN_B3 -to D[4]   #B3,LIN4,LVL4,D4
set_location_assignment PIN_A4 -to D[3]   #A4,LIN5,LVL3,D3
set_location_assignment PIN_B4 -to CS0_N  #B4,LIN6,LVL21,CS0_N
set_location_assignment PIN_A5 -to CS1    #A5,LIN7,LVL9,CS1
set_location_assignment PIN_B5 -to IRQ    #B5,LIN8,LVL14,IRQ_N
set_location_assignment PIN_A6 -to W_N    #A6,LIN9,LVL15,RW
set_location_assignment PIN_B6 -to SOD    #B6,LIN10,LVL13,SOD
set_location_assignment PIN_A7 -to ACLK   #A7,LIN11,LVL12,ACLK
set_location_assignment PIN_B7 -to BCLK   #B7,LIN12,LVL11,BCLK
set_location_assignment PIN_A8 -to A[3]   #A8,LIN13,LVL16,A3
set_location_assignment PIN_A9 -to SID    #A9,LIN14,LVL10,SID
set_location_assignment PIN_A10 -to D[2]  #A10,LIN15,LVL2,D2
set_location_assignment PIN_B10 -to D[1]  #B10,LIN16,LVL1,D1
set_location_assignment PIN_A11 -to D[0]  #A11,LIN17,LVL0,D0
set_location_assignment PIN_B11 -to A[0]  #B11,LIN18,LVL19,A0
set_location_assignment PIN_A12 -to EXT[1] #A12,LIN19,LVL23,EXT3
set_location_assignment PIN_B12 -to A[1]  #B12,LIN20,LVL18,A1
set_location_assignment PIN_B13 -to EXT[2] #B13,LIN21,LVL22,EXT2
set_location_assignment PIN_C11 -to AUD[1] #C11,AUD1,AUDF1,AUD
set_location_assignment PIN_D11 -to AUD[3] #D11,AUD2,AUDF4,AUDEXT2
set_location_assignment PIN_C12 -to AUD[4] #C12,AUD3,AUDF2,AUDEXT3
set_location_assignment PIN_D12 -to AUD[2] #D12,AUD4,AUDF3,AUDEXT1
set_location_assignment PIN_C13 -to A[2]   #C13,LIN22,LVL17,A2
set_location_assignment PIN_D13 -to EXT[3] #D13,LIN23,LVL20,EXT1
set_location_assignment PIN_N2 -to PADDLE[5]  #N2,PIN3,POT7,P5
set_location_assignment PIN_N3 -to PADDLE[1]  #N3,PIN2,POT6,P1
set_location_assignment PIN_N4 -to PADDLE[4]  #N4,PIN0,POT5,P4
set_location_assignment PIN_N5 -to PADDLE[7]  #N5,PIN1,POT4,P7
set_location_assignment PIN_N6 -to PADDLE[6]  #N6,PIN7,POT3,P6
set_location_assignment PIN_N7 -to PADDLE[0]  #N7,PIN6,POT2,P0
set_location_assignment PIN_N8 -to PADDLE[3]  #N8,PIN4,POT1,P3,
set_location_assignment PIN_N9 -to PADDLE[2]  #N9,PIN5,POT0,P2
set_location_assignment PIN_N10 -to POTRESET_N  #N10,POTRESET_N,
set_location_assignment PIN_N11 -to IOX_RST   #N11,IOX_RST,
set_location_assignment PIN_N12 -to IOX_SDA   #N12,IOX_SDA,
set_location_assignment PIN_M13 -to IOX_SCL   #M13,IOX_SCL,
set_location_assignment PIN_L13 -to IOX_INT   #L13,IOX_INT,
set_location_assignment PIN_G9 -to CLK_SLOW
set_location_assignment PIN_H8 -to CLK_OUT

set_instance_assignment -name WEAK_PULL_UP_RESISTOR ON -to IOX_RST
set_instance_assignment -name WEAK_PULL_UP_RESISTOR ON -to IOX_INT
set_instance_assignment -name WEAK_PULL_UP_RESISTOR ON -to IOX_SDA
set_instance_assignment -name WEAK_PULL_UP_RESISTOR ON -to IOX_SCL

set_instance_assignment -name WEAK_PULL_UP_RESISTOR ON -to PADDLE[0]
set_instance_assignment -name WEAK_PULL_UP_RESISTOR ON -to PADDLE[1]
set_instance_assignment -name WEAK_PULL_UP_RESISTOR ON -to PADDLE[2]
set_instance_assignment -name WEAK_PULL_UP_RESISTOR ON -to PADDLE[3]
set_instance_assignment -name WEAK_PULL_UP_RESISTOR ON -to PADDLE[4]
set_instance_assignment -name WEAK_PULL_UP_RESISTOR ON -to PADDLE[5]
set_instance_assignment -name WEAK_PULL_UP_RESISTOR ON -to PADDLE[6]
set_instance_assignment -name WEAK_PULL_UP_RESISTOR ON -to PADDLE[7]

set_instance_assignment -name CURRENT_STRENGTH_NEW "MAXIMUM CURRENT" -to AUD[1]
set_instance_assignment -name CURRENT_STRENGTH_NEW "MAXIMUM CURRENT" -to AUD[2]
set_instance_assignment -name CURRENT_STRENGTH_NEW "MAXIMUM CURRENT" -to AUD[3]
set_instance_assignment -name CURRENT_STRENGTH_NEW "MAXIMUM CURRENT" -to AUD[4]
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

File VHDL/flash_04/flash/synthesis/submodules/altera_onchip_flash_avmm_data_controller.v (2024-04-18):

// (C) 2001-2019 Intel Corporation. All rights reserved.
// Your use of Intel Corporation's design tools, logic functions and other 
// software and tools, and its AMPP partner logic functions, and any output 
// files from any of the foregoing (including device programming or simulation 
// files), and any associated documentation or information are expressly subject 
// to the terms and conditions of the Intel Program License Subscription 
// Agreement, Intel FPGA IP License Agreement, or other applicable 
// license agreement, including, without limitation, that your use is for the 
// sole purpose of programming logic devices manufactured by Intel and sold by 
// Intel or its authorized distributors.  Please refer to the applicable 
// agreement for further details.


////////////////////////////////////////////////////////////////////
//
//  ALTERA_ONCHIP_FLASH_AVMM_DATA_CONTROLLER (PARALLEL-to-PARALLEL MODE)
//
//  Copyright (C) 1991-2013 Altera Corporation
//  Your use of Altera Corporation's design tools, logic functions 
//  and other software and tools, and its AMPP partner logic 
//  functions, and any output files from any of the foregoing 
//  (including device programming or simulation files), and any 
//  associated documentation or information are expressly subject 
//  to the terms and conditions of the Altera Program License 
//  Subscription Agreement, Altera MegaCore Function License 
//  Agreement, or other applicable license agreement, including, 
//  without limitation, that your use is for the sole purpose of 
//  programming logic devices manufactured by Altera and sold by 
//  Altera or its authorized distributors.  Please refer to the 
//  applicable agreement for further details.
//
////////////////////////////////////////////////////////////////////

// synthesis VERILOG_INPUT_VERSION VERILOG_2001

`timescale 1 ps / 1 ps

module altera_onchip_flash_avmm_data_controller (
    // To/From System
    clock,
    reset_n,
    
    // To/From Flash IP interface
    flash_busy,
    flash_se_pass,
    flash_sp_pass,
    flash_osc,
    flash_drdout,
    flash_xe_ye,
    flash_se,
    flash_arclk,
    flash_arshft,
    flash_drclk,
    flash_drshft,
    flash_drdin,
    flash_nprogram,
    flash_nerase,
    flash_ardin,
        
    // To/From Avalon_MM data slave interface
    avmm_read,
    avmm_write,
    avmm_addr,
    avmm_writedata,
    avmm_burstcount,
    avmm_waitrequest,
    avmm_readdatavalid,
    avmm_readdata,
        
    // To/From Avalon_MM csr slave interface
    csr_control,
    csr_status
);

    parameter READ_AND_WRITE_MODE = 0;
    parameter WRAPPING_BURST_MODE = 0;
    parameter DATA_WIDTH = 32;
    parameter AVMM_DATA_ADDR_WIDTH = 20;
    parameter AVMM_DATA_BURSTCOUNT_WIDTH = 4;
    parameter FLASH_ADDR_WIDTH = 23;
    parameter FLASH_SEQ_READ_DATA_COUNT = 2; //number of 32-bit data per sequential read
    parameter FLASH_READ_CYCLE_MAX_INDEX = 3; //period to for each sequential read
    parameter FLASH_ADDR_ALIGNMENT_BITS = 1; //number of last addr bits for alignment
    parameter FLASH_RESET_CYCLE_MAX_INDEX = 28; //period that required by flash before back to idle for erase and program operation
    parameter FLASH_BUSY_TIMEOUT_CYCLE_MAX_INDEX = 112; //flash busy timeout period (1200ns)
    parameter FLASH_ERASE_TIMEOUT_CYCLE_MAX_INDEX = 40603248; //erase timeout period (350ms)
    parameter FLASH_WRITE_TIMEOUT_CYCLE_MAX_INDEX = 35382; //write timeout period (305us)
    parameter MIN_VALID_ADDR = 1;
    parameter MAX_VALID_ADDR = 1;
    parameter SECTOR1_START_ADDR = 1;
    parameter SECTOR1_END_ADDR = 1;
    parameter SECTOR2_START_ADDR = 1;
    parameter SECTOR2_END_ADDR = 1;
    parameter SECTOR3_START_ADDR = 1;
    parameter SECTOR3_END_ADDR = 1;
    parameter SECTOR4_START_ADDR = 1;
    parameter SECTOR4_END_ADDR = 1;
    parameter SECTOR5_START_ADDR = 1;
    parameter SECTOR5_END_ADDR = 1;
    parameter SECTOR_READ_PROTECTION_MODE = 5'b11111;
    parameter SECTOR1_MAP = 1;
    parameter SECTOR2_MAP = 1;
    parameter SECTOR3_MAP = 1;
    parameter SECTOR4_MAP = 1;
    parameter SECTOR5_MAP = 1;
    parameter ADDR_RANGE1_END_ADDR = 1;
    parameter ADDR_RANGE2_END_ADDR = 1;
    parameter ADDR_RANGE1_OFFSET = 1;
    parameter ADDR_RANGE2_OFFSET = 1;
    parameter ADDR_RANGE3_OFFSET = 1;

    localparam [1:0]    ERASE_ST_IDLE = 0,
                        ERASE_ST_PENDING = 1,
                        ERASE_ST_BUSY = 2;

    localparam [1:0]    STATUS_IDLE = 0,
                        STATUS_BUSY_ERASE = 1,
                        STATUS_BUSY_WRITE = 2,
                        STATUS_BUSY_READ = 3;

    localparam [2:0]    WRITE_STATE_IDLE = 0,
                        WRITE_STATE_ADDR = 1,
                        WRITE_STATE_WRITE = 2,
                        WRITE_STATE_WAIT_BUSY = 3,
                        WRITE_STATE_WAIT_DONE = 4,
                        WRITE_STATE_RESET = 5,
                        WRITE_STATE_ERROR = 6;

    localparam [2:0]    ERASE_STATE_IDLE = 0,
                        ERASE_STATE_ADDR = 1,
                        ERASE_STATE_WAIT_BUSY = 2,
                        ERASE_STATE_WAIT_DONE = 3,
                        ERASE_STATE_RESET = 4,
                        ERASE_STATE_ERROR = 5;

    localparam [2:0]    READ_STATE_IDLE = 0,
                        READ_STATE_ADDR = 1,
                        READ_STATE_READ = 2,
                        READ_STATE_SETUP = 2,
                        READ_STATE_DUMMY = 3,
                        READ_STATE_READY = 4,
                        READ_STATE_FINAL = 5,
                        READ_STATE_CLEAR = 6,
                        READ_STATE_PULSE_SE = 7;

    localparam [0:0]    READ_SETUP = 0,
                        READ_RECV_DATA = 1;

    localparam [1:0]    READ_VALID_IDLE = 0,
                        READ_VALID_READING = 1,
                        READ_VALID_PRE_READING = 2;

    // To/From System
    input clock;
    input reset_n;
    
    // To/From Flash IP interface
    input flash_busy;
    input flash_se_pass;
    input flash_sp_pass;
    input flash_osc;
    input [DATA_WIDTH-1:0] flash_drdout;
    output flash_xe_ye;
    output flash_se;
    output flash_arclk;
    output flash_arshft;
    output flash_drclk;
    output flash_drshft;
    output flash_drdin;
    output flash_nprogram;
    output flash_nerase;
    output [FLASH_ADDR_WIDTH-1:0] flash_ardin;
        
    // To/From Avalon_MM data slave interface
    input avmm_read;
    input avmm_write;
    input [AVMM_DATA_ADDR_WIDTH-1:0] avmm_addr;
    input [DATA_WIDTH-1:0] avmm_writedata;
    input [AVMM_DATA_BURSTCOUNT_WIDTH-1:0] avmm_burstcount;
    output avmm_waitrequest;
    output avmm_readdatavalid;
    output reg [DATA_WIDTH-1:0] avmm_readdata;
        
    // To/From Avalon_MM csr slave interface
    input [31:0] csr_control;
    output [9:0] csr_status;
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

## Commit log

2024-04-17 Initial push of KiCad import of PokeyMax 4 files
    [ADC.kicad_sch, Audio_filter.kicad_sch, Decoupling.kicad_sch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]
2024-04-18 Add VHDL
    [6581.csv, 8580.csv, WAVE1.CSV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]
2024-08-10 Update the v4 board
    [ADC.kicad_sch, Audio_filter.kicad_sch, Decoupling.kicad_sch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]
2024-08-18 Updates for JLCPCB fabrication and parts library
    [ADC.kicad_sch, Audio_filter.kicad_sch, Decoupling.kicad_sch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]
2024-08-21 Final adjustements to production files for JLC
    [Audio_filter.kicad_sch, FPGA.kicad_sch, Level_conv.kicad_sch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]
2024-08-21 Nothing really
    [pokeymax4.kicad_pcb]
2024-08-22 Update BOM from 0402 to 0603 where relevant
    [ADC.kicad_sch, Audio_filter.kicad_sch, Decoupling.kicad_sch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]
2024-08-25 Pokeymax 4s WIP
    [ADC.kicad_sch, Audio_filter.kicad_sch, Decoupling.kicad_sch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]
2024-08-25 Complete routing of Pokeymax 4s
    Removed backup dirs from repo
    [PokeyMax4s.kicad_pcb]
2024-08-25 PokeyMax 4s silkscreen
    [PokeyMax4s.kicad_pcb]
2024-08-25 PokeyMax 4s fabrication files
    [ADC.kicad_sch, Audio_filter.kicad_sch, Level_conv.kicad_sch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]
2024-08-27 Add A4 to PokeyMax 4s
    Reroute accordingly
    [ADC.kicad_sch, Audio_filter.kicad_sch, Level_conv.kicad_sch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]
2024-08-28 Last adjustments to 4s
    [PokeyMax4s.kicad_pcb, positions.csv]
2024-08-28 Fix typo on 4s board
    [PokeyMax4s.kicad_pcb]
2025-06-21 Fix LIN22 to AUD1 erroneous connection
    [ADC.kicad_sch, Audio_filter.kicad_sch, Decoupling.kicad_sch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]
2025-06-21 Bump rev number to 1.1
    [Audio_filter.kicad_sch, PokeyMax4s.kicad_pcb]

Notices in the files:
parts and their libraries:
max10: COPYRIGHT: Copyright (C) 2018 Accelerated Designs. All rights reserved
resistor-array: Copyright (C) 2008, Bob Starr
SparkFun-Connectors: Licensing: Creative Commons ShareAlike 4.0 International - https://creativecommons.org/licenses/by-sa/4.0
